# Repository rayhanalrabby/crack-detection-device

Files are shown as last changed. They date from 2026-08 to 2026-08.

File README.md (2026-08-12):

# Crack Detection Device

A low-cost ultrasonic surface-crack detector: an HC-SR04 on an Arduino
Uno inside a custom 3D-printed enclosure. Built as an accessible
alternative to commercial NDT equipment, which starts around €100 and
runs far higher for professional units.

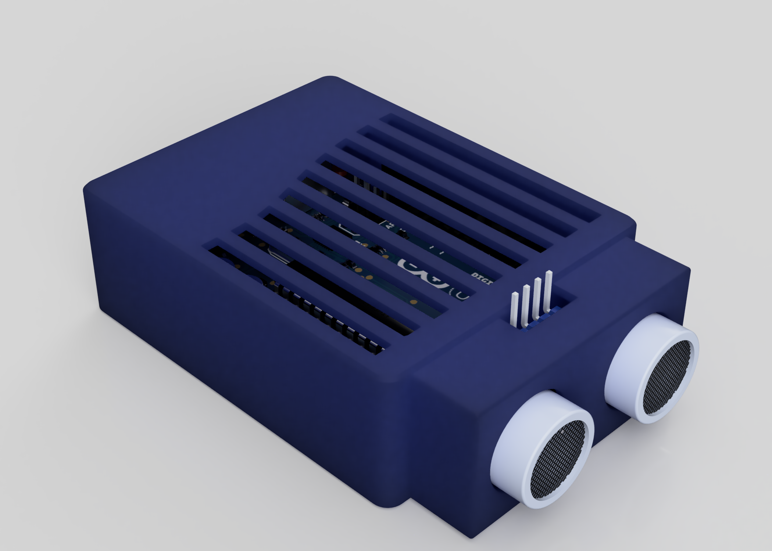
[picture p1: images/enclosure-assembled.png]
Enclosure


## Why

Commercial crack detection works — ultrasonic pulse flaw detectors and
eddy current testers both do the job well — but they're priced for
professional inspection contracts, which puts them out of reach for
small projects and routine checks.

A pre-development survey of construction, manufacturing, and QA
workers alongside home-improvement users found the two most-wanted
features were **portability** and **low cost**, ahead of severity
classification and data logging. That result set the design brief:
small, simple, cheap.

The project targets UN SDG 9 (Industry, Innovation and Infrastructure).
Undetected structural cracks carry a real cost — the Rana Plaza
collapse in 2013 followed visible wall cracks that were dismissed the
day before the building came down.

## How it works

The HC-SR04 emits ultrasonic pulses and times the echo. Swept across a
surface, a crack registers as a spike in measured distance: the sound
path lengthens where the surface recedes. The Arduino IDE's serial
plotter renders this live, so a crack appears as a visible deviation
from an otherwise flat trace.

| No crack | Crack detected |
|:---:|:---:|
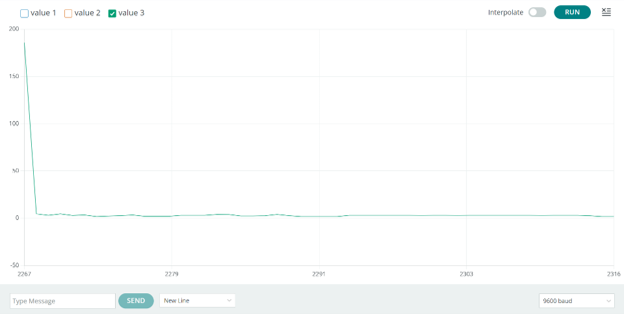
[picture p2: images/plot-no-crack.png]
Flat trace
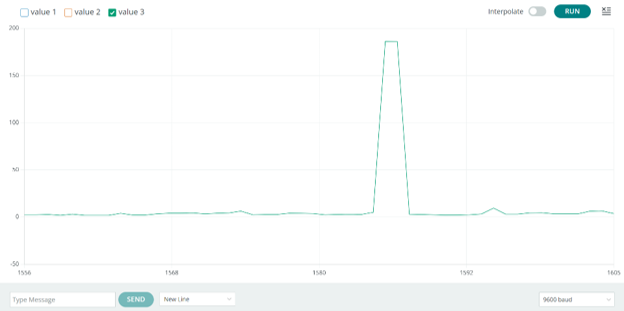
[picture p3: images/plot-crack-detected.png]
Spike
|  |  |

## Sensor validation

Before building anything, the sensor was checked against its datasheet
claim of ±3 mm accuracy across 2–400 cm. Testing focused on the short
end of that range, since surface crack detection never uses the rest.

| Actual (cm) | Measured (cm) | Error (cm) |
|---|---|---|
| 0.5 | 0.49 | 0.01 |
| 1.0 | 1.04 | −0.04 |
| 2.0 | 1.99 | 0.01 |
| 2.5 | 2.35 | 0.15 |
| 3.0 | 3.01 | 0.01 |
| 3.6 | 3.59 | 0.01 |
| 8.0 | 7.79 | 0.21 |

Worst case 2.1 mm, inside the datasheet's 3 mm. Worth noting the
readings at 0.5 cm and 1.0 cm sit below the sensor's rated 2 cm
minimum and shouldn't be treated as valid — the HC-SR04 has a blind
zone there where the echo returns before the receiver settles.

## Enclosure

Designed in Fusion 360 around the Arduino Uno's mounting footprint,
printed in PLA as a two-part snap-fit shell.

<p align="center">
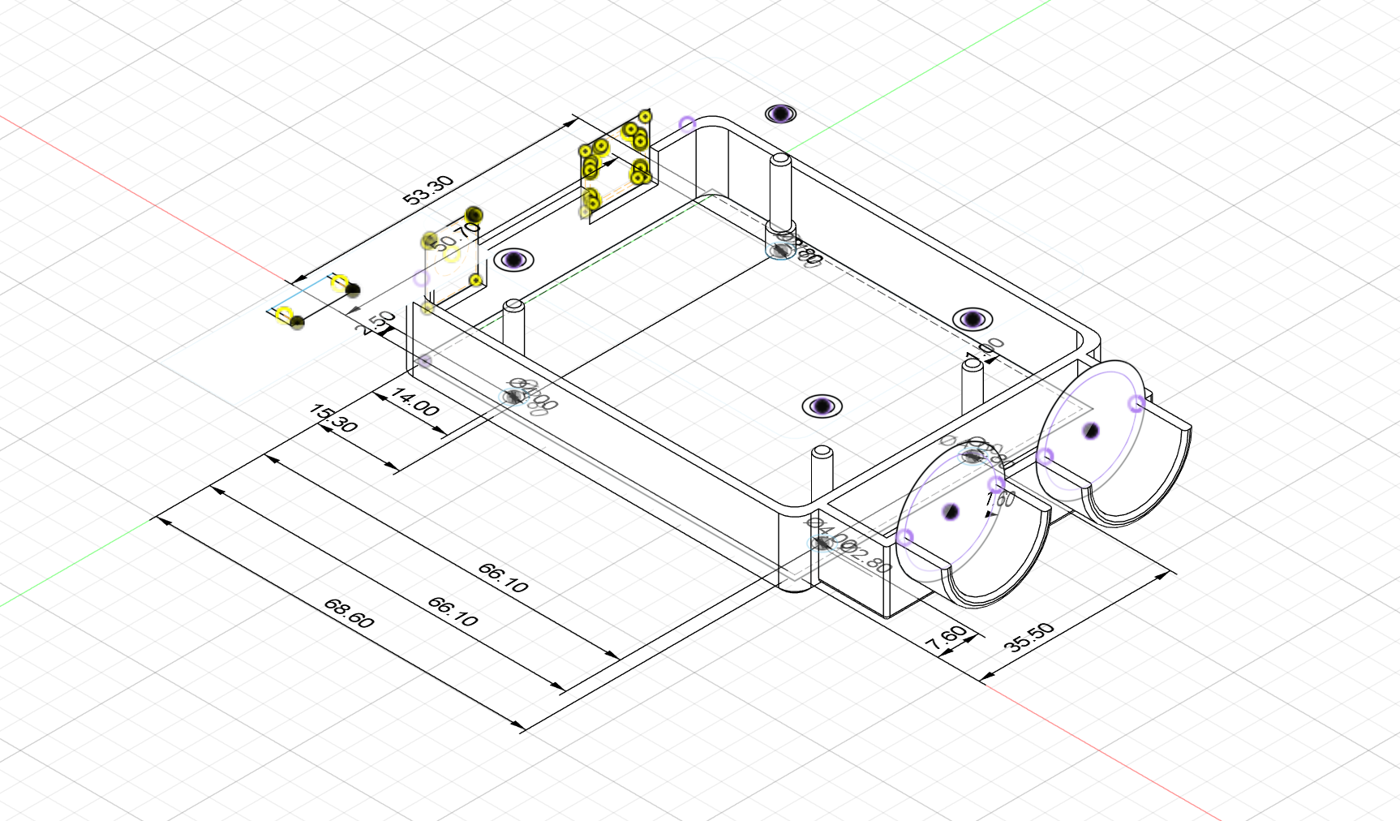
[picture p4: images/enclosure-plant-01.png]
  
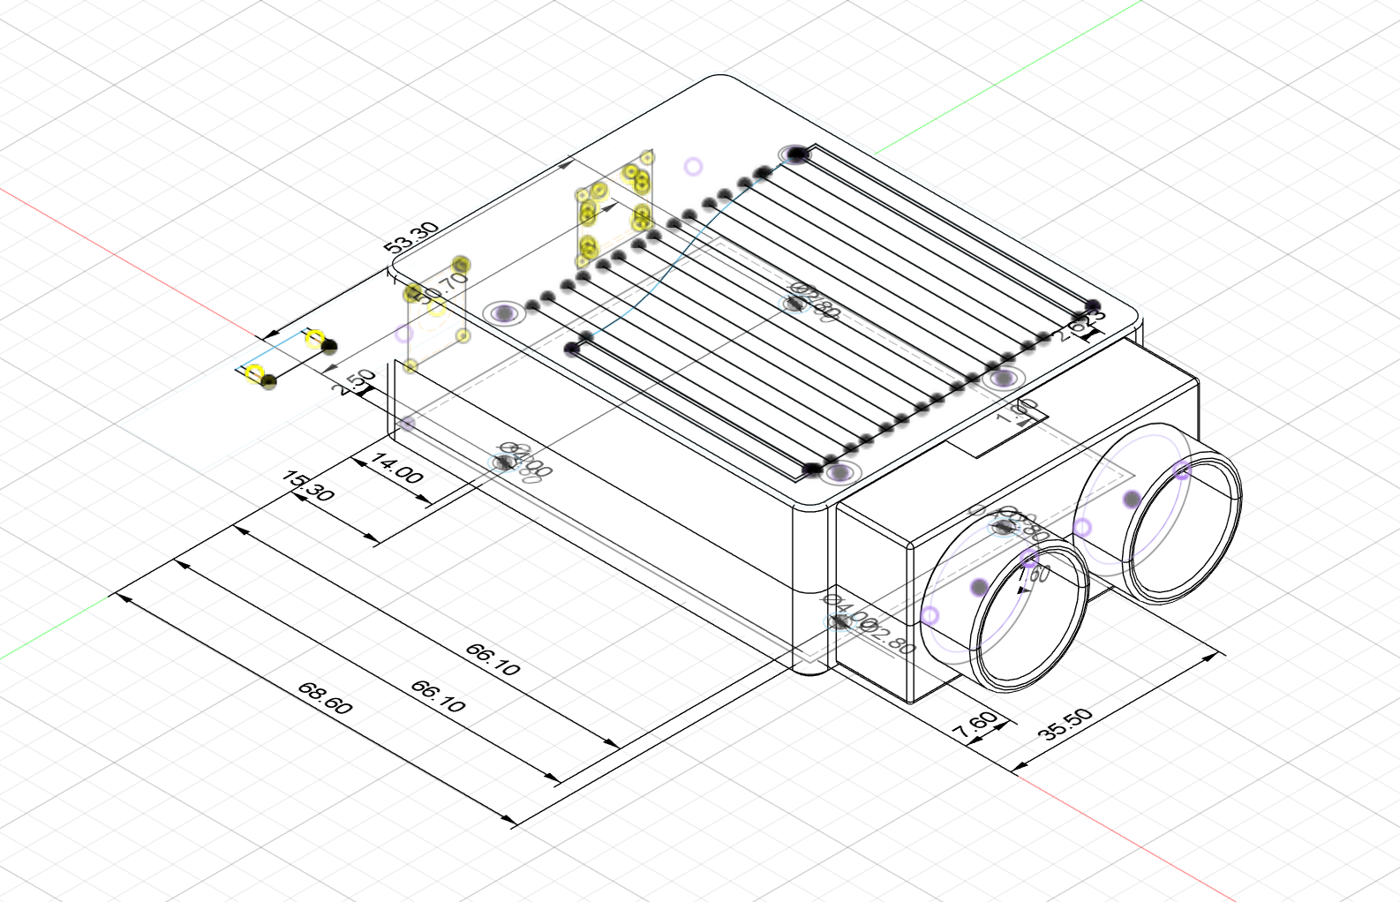
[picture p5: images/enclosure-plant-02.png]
  
</p>

| Feature | Value | Reasoning |
|---|---|---|
| External | 68.6 × 53.3 × 22.0 mm | Arduino footprint plus clearance |
| Wall thickness | 1.6 mm | Exactly 4 perimeters at a 0.4 mm nozzle |
| Internal clearance | 1.0 mm | Print shrinkage and insertion tolerance |
| Mounting pins | Ø2.8 mm | Under the board's Ø3.2 mm holes — friction fit, not press fit |
| Standoffs | Ø4.0 × 4.0 mm | Keeps solder joints off the floor |
| Snap-fit overlap | 4.0 mm, chamfered | Guides pins in, prevents print damage on assembly |
| Ventilation | 9 slots, 3.5 mm | Airflow without compromising the shell |

Every dimension was chosen against a manufacturing constraint rather
than picked by eye. The 1.6 mm wall is two perimeters either side at a
0.4 mm nozzle — strong without wasting material. The pins are
deliberately undersized against the Arduino's holes so the board
friction-fits and can still be removed.

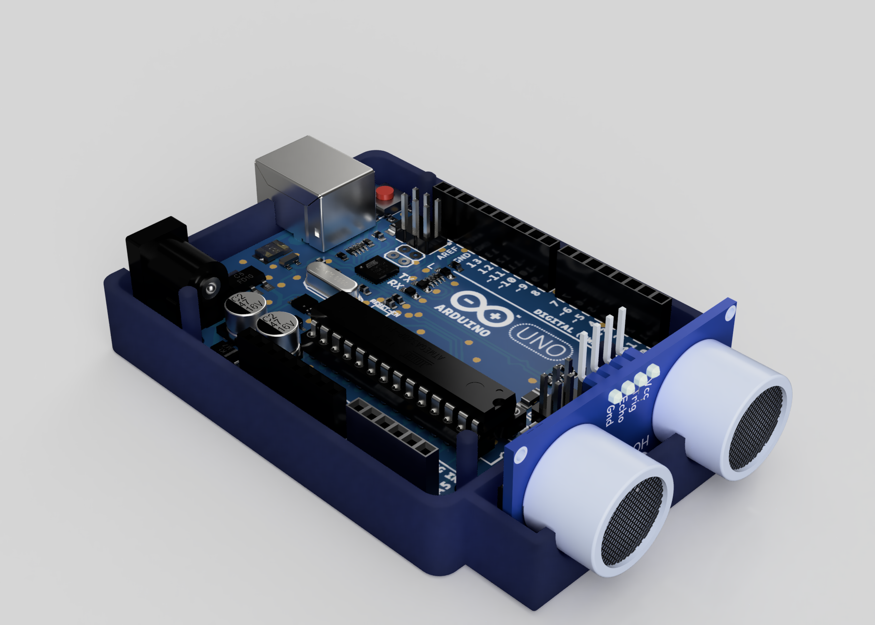
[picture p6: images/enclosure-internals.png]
Internals


The sensor housing extends 12.6 mm from the body with the barrel
seated 9.0 mm deep, holding the transducers at fixed geometry relative
to the enclosure — important, since sweep distance is the measurement.
Cut-outs on the top expose the programming header, so the board can be
reflashed without opening the case.

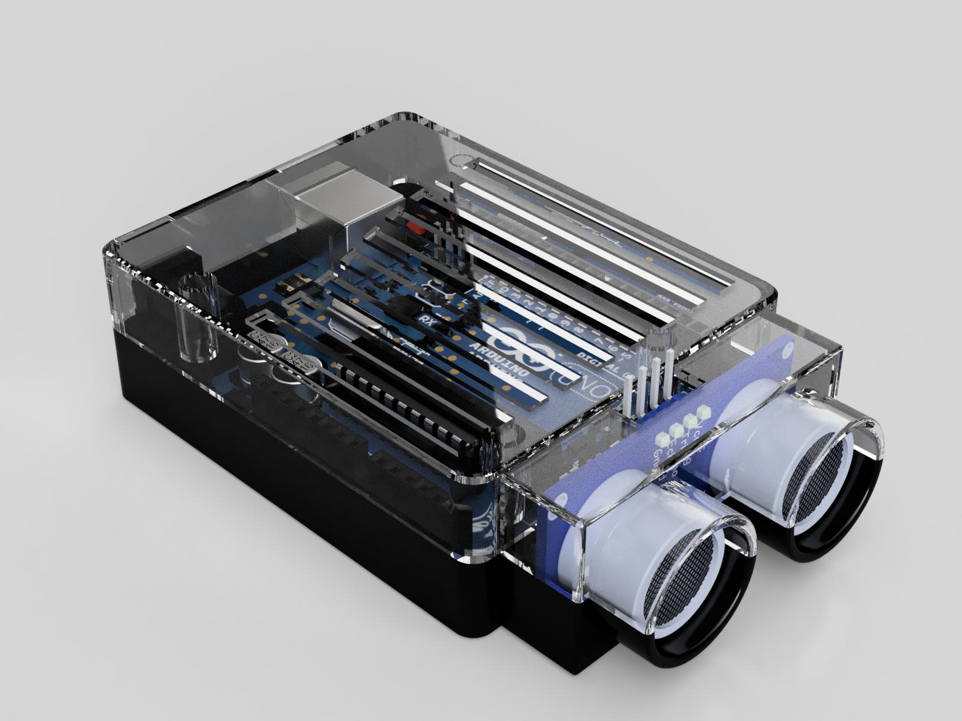
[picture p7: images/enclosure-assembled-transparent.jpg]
Transparent view


## Validation with users

A post-development survey put the prototype in front of the same kinds
of users as the initial one. Feedback was positive on ease of use and
build quality, with two recurring requests: **data storage** across
repeated checks on one area, and **more detailed output** for
reporting.

Both had ranked below portability and cost in the pre-development
survey. They only surfaced as priorities once people had something in
their hands — which is the case for building the prototype at all
rather than designing from the first survey and stopping.

## What I'd change

- **The device detects surface geometry, not cracks.** A step, a seam,
  or a texture change produces the same spike as a fracture. Nothing
  distinguishes them, which limits it to guided use on surfaces the
  operator already knows should be flat.
- **No severity classification**, despite it ranking third in user
  demand. Depth and width determine whether a crack matters, and a
  single-point distance reading gives neither.
- **Sub-2 cm readings are outside the sensor's rated range** and were
  included in the accuracy table anyway. They shouldn't have been.
- **Detection is by eye, off a plotter.** No thresholding, no logging,
  no output beyond a live graph — precisely the two things users asked
  for after handling the prototype.

## Hardware
Arduino Uno · HC-SR04 ultrasonic sensor · 3D-printed PLA enclosure

## Files
- `src/crack_detector.cpp` — sensor firmware
- `cad/` — printable enclosure, two parts (snap-fit)
- `docs/technical-report.pdf` — research, testing, design, survey data
- `docs/problem-specification.pdf` — original project brief
- [`media/enclosure-render.mp4`](media/enclosure-render.mp4) — enclosure render
- [`media/presentation-recording.mp4`](media/presentation-recording.mp4) — group presentation
- `images/` — renders, dimensioned drawings, serial plots

---

EE397 Project-Based Learning, Maynooth University, Year 3 Semester 1
(Dec 2025). Group of 3 — my contribution: enclosure design (Fusion 360
modelling, dimensioning, print preparation), firmware, and research.
Full team credited in the report.

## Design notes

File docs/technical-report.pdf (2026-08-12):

## Crack Detection

## EE397 Technical Report

## Group 5: Patricia Ehigiamusoe Shakirat Olayode Md Rayhan Mia

## Facilitator: Vahid Fakhari

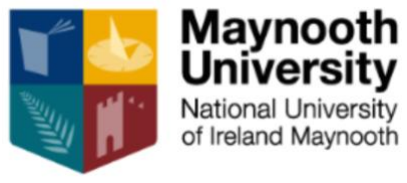
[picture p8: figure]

19/12/2025

## Department of Electronic Engineering Maynooth University

## ABSTRACT

The aim of this report is to present a possible solution to a societal issue, aligned with the Sustainable Development Goals (SDGs). The solution must be well researched and extensively tested to determine how well is addresses a certain issue or part of an issue. Sustainable infrastructure is a key part of any type of construction. From physical buildings to web applications, every developer works to have infrastructure that is easily maintainable and will not fail unexpectedly. One aspect of maintenance is testing for irregularities. This should be done during development as well as on a regular basis after development is complete.
Looking at the area of infrastructure sustainability, we decided on a crack detection device. Such a device detects surface level cracks within a degree of accuracy. This report details our findings in this area as well as our efforts to create a crack detecting device.
Throughout this report, the research behind a crack detection device and the construction of our device will be demonstrated.

## TABLE OF CONTENTS

## 1. INTRODUCTION

Crack, break, fracture, split. These are not words we want to hear in any building or manufacturing process. Nowadays, we are so used to seeing cracks all around us. For example, in our homes, in buildings, and on bridges. Some are big, but many are so small we don’t think twice about them. But these miniature fractures can lead to major issues if left unchecked and the first step in addressing any problem is being aware of the problem. This is our motivation for developing a crack detection device. We are aware that many versions of similar devices exist. However, they are usually expensive and therefore not accessible for projects with a smaller budget. By developing a device at a lower cost and that is simple to use, we hope to make crack detection more accessible.
This aims of this project align with the 9

th Sustainable Development Goal (SDG), Industry, Innovation, and Infrastructure. We will reflect on the social and environmental impact cracks and fractures have on infrastructure.
In this report, we will discuss the theoretical aspect of crack detection as well as the technical work carried out to create a prototype device.

## 2. REPORT LAYOUT

The rest of this report is structured as follows:

- In section 3, a detailed review of the crack detection field is investigated. Examples of existing devices are looked at. This provides a strong basis for the project to be built on.
- Section 4 covers the ethical considerations surrounding this project, including a related Sustainable Development Goal (SDG), Industry, Innovation and Infrastructure. This section aims to examine the role of maintenance and sustainability in society.
- In section 5, customer input is gathered via survey. An analysis of public awareness and opinion of infrastructure issues and their solutions provide valuable insights into the necessity of this project.
- In section 6, the development of our first prototype is discussed. This includes sensor testing and the design of an external cover.
- Section 7 presents customer feedback of the prototype. A new post-development survey is compared to the initial survey carried out at the beginning of the project.
- Finally, section 8 highlights the main findings of this project in a conclusion. Possible further works are also explored in this section.

## 3. LITERATURE REVIEW

Looking at available crack detection devices will further broaden our understanding of crack detection technology and how such a device would need to be developed. This review will explore different types of crack detection which will help us decide the best option to use for our project.

3.1. Concrete Ultrasonic Pulse Flaw Detector

The Concrete Ultrasonic Pulse Flaw Detector for Crack Depth and Width is a device sold by GAOTek [1]. It is advertised as an “advanced ultrasonic flaw detector with 1-12,000mm range”. Some of the parts it consists of are an LCD, a crack width probe, a crack depth gauge scale and couplant. The device works by reading the data with the transducer (probe) and displaying it on screen. A couplant (gel like substance) is used to improve the transmission of ultrasonic waves between the probe and material being tested [2]. There is no price listed for this product, there is only an option on their website to request a quote. However, we can imagine the price point of a device like this would be high.

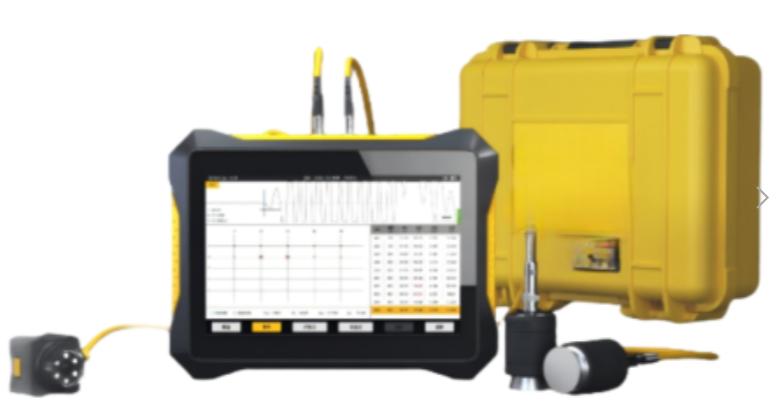
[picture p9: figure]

Figure 1: Concrete Ultrasonic Pulse Flaw Detector for Crack Depth and Width

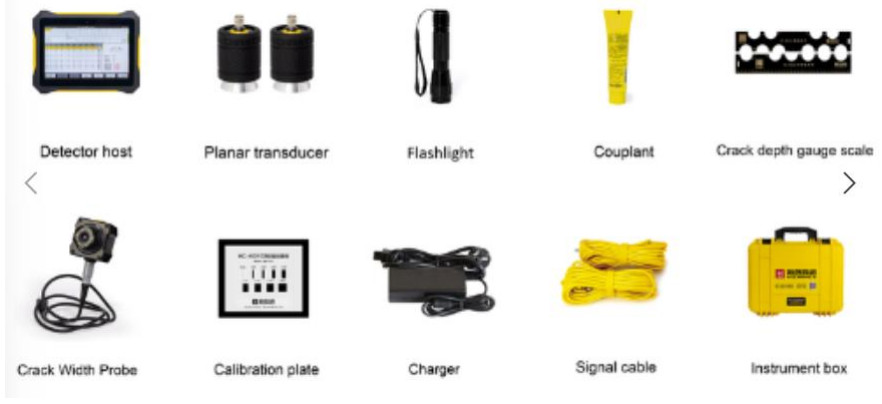
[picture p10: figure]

Figure 2: Parts included in Concrete Ultrasonic Pulse Flaw Detector

3.2.Eddy Current Testing (ECT)

Crack detecting products developed by Eddyfi Technologies use a technique called eddy current testing (ECT) [3]. ECT involves a passing alternating current through a copper wire which creates a magnetic field around the wire [4]. The current in the wire and the magnetic field oscillate at the same frequency. If the coil is brought near other conductive materials, the opposing currents create eddy currents. Defects are detected by analysing the change in the magnetic fields. They state that is type of testing offers “fast inspection of surface-breaking cracks”.

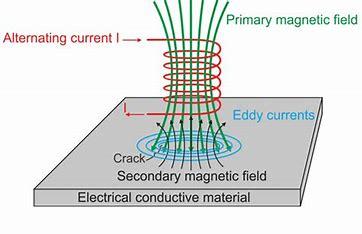
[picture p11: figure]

Figure 3: Eddy Current Testing (ECT)

By researching some available methods of crack detection, we have settled on using an ultrasonic sensor for our project. The straight-forward approach of the sensor is suitable for this project. The Arduino ultrasonic sensor can be easily coded and tested with a compatible microcontroller.
Ultrasonic crack detection which is a method of non-destructive testing (NDT) [5]. NDT is a form of testing that does not impact the test material, unlike destructive testing. Destructive testing evaluates the test material properties by forcing the properties (e.g. tensile strength) to reach their limit.

## 4. ETHICAL CONSIDERATIONS

4.1.Sustainable Development Goals (SDGs)

Part of the given criterion for this project was to provide a potential solution to a community-based problem. The Sustainable Development Goals (SDGs) are a set of seventeen global goals arranged by the United Nations [6]. These goals seek to tackle various global challenges, like No Poverty, Zero Hunger, Quality Education, and many more. The SDGs act as a “universal call to action to end poverty, protect the planet, and ensure prosperity for all” [6].
For this assignment, we choose to consider the 9th Sustainable Development Goal, ’Industry, Innovation, and Infrastructure’. The aim of this goal is to “build resilient infrastructure, promote inclusive and sustainable industrialisation and foster innovation” [7]. A crack detector device can be used to test the integrity of materials before, during and after construction.
4.2. Societal Problems

A societal problem is defined as “a condition or situation that negatively affects a significant number of people in society” [8]. Poor infrastructure conditions is an issue many people face. Many of the buildings we live and work in are left in poor conditions which can be a danger to people in them. In extreme cases the buildings can become unusable and left abandoned. This is a problem that can stem from different issues including the presence of small cracks or faults which worsen over time. One correct procedure to deal with such an issue is to regularly check the state of a building with a device like a crack detector to identify areas before they intensify.

With our device a user will be able to detect the issue early, limiting the potential permanent damages. The simple design and functionality make it easy to use so it’s use is not restricted to just professionals.

4.3. Environment

Cracks and other structural defects play a major role in our environment today, more than we realise. The structural defects in buildings and other establishments have far-reaching impacts on the societal and economic infrastructure of the world. It affects public safety, service continuity and long-term development. The lack of considerations regarding the severity of “minor cracks” can lead to major safety issues and injuries or in some extreme cases death.
Examples of such cases include the collapse of the eight-storey Rana Plaza Factory in Bangladesh on 23rd April 2013. The building was evacuated due to the appearing of cracks in the walls the day before this mishap. However, as a result of failure to recognise the severity of the situation, workers were permitted back inside the following day. Disastrously, the building collapsed and resulted in significant loss of life [9]. The presence of these external cracks indicate that the structural integrity of the building had been compromised prior to this incident. If the cracks were detected earlier, the situation could have potentially been avoided.
There are multiple others severe cases similar to the Rana Plaza Factory case. For example, a sinkhole in Thailand in September 2025 [10] and the collapse of a bridge in China in July 2024 [11]. All these fatalities developed from construction oversights, including inadequate planning and insufficient long-term structural considerations. Over time, the emergence of cracks and structural decay led to fatal outcomes.
A possible solution to problems like this is a crack detector device. With this device, it is simple to check for cracks in most structures. This device is one step closer to a safer living environment.

## 5. CUSTOMER INPUT

When developing a product for public use, it is vital to consider who the end user will be. The target audience we looked at included professionals working in fields like construction, manufacturing and quality control, as well as people who engage in advanced home projects. We wanted a device that is suitable for both these groups. We first organised a collection of questions to ask people who might use a device like this. When choosing the questions, we wanted to assess the participants knowledge of crack detection and explore what features they would like in the device. We conducted a short survey to inform decisions later on in the project. The results of this survey are detailed below.

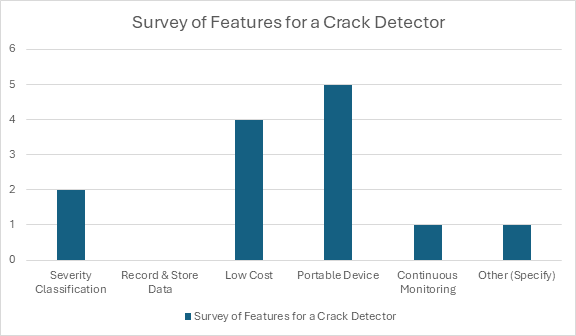
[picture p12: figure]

Figure 1: Desired Features in a Crack Detector from Survey

The graph above (Figure 1) shows the desired features chosen by the participants. They were given multiple options and could pick as many as they like. The most popular choice was a portable device. Another common choice was low cost. The customer input gathered from this survey defined the design of our prototype. We aimed to make the device small, easy to handle, portable and at a low price since those were the features chosen by most of the participants.

Outside of device features, 80% of respondents said they had heard of crack detecting tools. All participants said they would trust a device to detect cracks. This represents a level of trust and expectation in modern technology. People expect devices to be accurate and function well. This is something we considered when creating a prototype.

## 6. PROTOTYPE DEVELOPMENT

6.1. Sensors

Sensors are input devices that can monitor physical signals and detect different types of changes in the environment. They are crucial inspecting the behaviour of a system and detecting unanticipated actions or failures in a system [12]. There are multiple different types of sensors but for this project we settled on using an ultrasonic sensor.

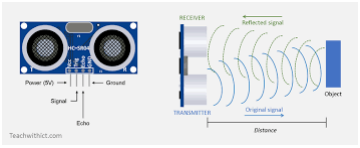
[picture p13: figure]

Figure 2: Ultrasonic Sensor

For the circuit, the HC-SR04 Ultrasonic Sensor was used. This sensor measures the distance by emitting high frequency sound waves and detecting their echo’s. The datasheet of the sensor claims the sensor can detect objects in the range of 2cm – 400cm [13]. By placing this sensor opposite a surface within the range of detection, it can detect cracks using the sound waves.

6.2. Circuit Design

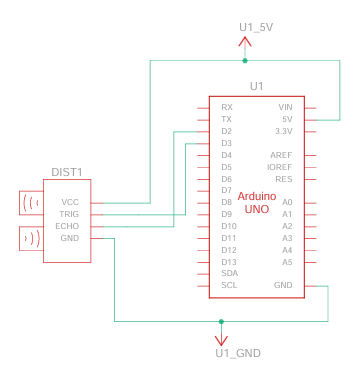
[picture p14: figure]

Figure 3: Circuit Wiring of Ultrasonic Sensor with Arduino UNO

The circuit components were composed of an ultrasonic sensor and an Arduino UNO microcontroller board. The code was written using the Arduino IDE [14]. The IDE provides a serial monitor and serial plotter. The monitor was used to check the printed distance values. The serial plotter was used to make a live graph of the data read from the ultrasonic sensor.

6.3. Testing Ultrasonic Sensor Accuracy

Since choosing to use an ultrasonic sensor, we needed to confirm the sensor we got operates as expected. The datasheet for the HC-SR04 Ultrasonic Sensor claims the operating range of the sensor is approximately 2cm to 400cm with ±3mm accuracy [15]. This test focuses on the lower side of the range. As the device is small, it will be limited to detecting smaller cracks. Therefore, the full range of the sensor will not be used. The details of the test to inspect the datasheet values are explained below.

Equipment Needed:

- Ultrasonic sensor
- Tape measure
- Arduino Uno
- Computer with Arduino IDE installed
- Object for sensor to detect

Method

- Choose a distance, measure the distance with a tape measure and record the value.
- Place an object at one end of the measured distance and the ultrasonic sensor at the other end.
- Run the code in Appendix C for the sensor to print values to the serial monitor and record the value.
- Comparing the actual distance to the value from the ultrasonic sensor distance to get the difference [Equation 1].
Difference = Actual distance − Ultrasonic sensor distance | [Equation 1]
Results
Actual Distance (cm) | Ultrasonic Sensor Distance (cm) | Difference (cm)
2 | 1.99 | 0.01
8 | 7.79 | 0.21
0.5 | 0.49 | 0.01
1 | 1.04 | -0.04
2.5 | 2.35 | 0.15
3 | 3.01 | 0.01
3.6 | 3.59 | 0.01

Table 1: Ultrasonic Sensor Accuracy Test Results

The result of the test shown in the table above (table 1), show the sensor is quite accurate. The biggest difference was 0.21cm, which converts to 2.1mm. This value is within the ±3mm error from the datasheet. It can be concluded that the ultrasonic sensor operates as expected.

6.4. Simulations

The below figures (figure 4 and figure 5) are graphs of the distance measured when a crack is not present and when it is present. It is displayed using the serial plotter tool in the Arduino IDE. The x-axis is the time in microseconds. The y-axis is the measured distance in mm.

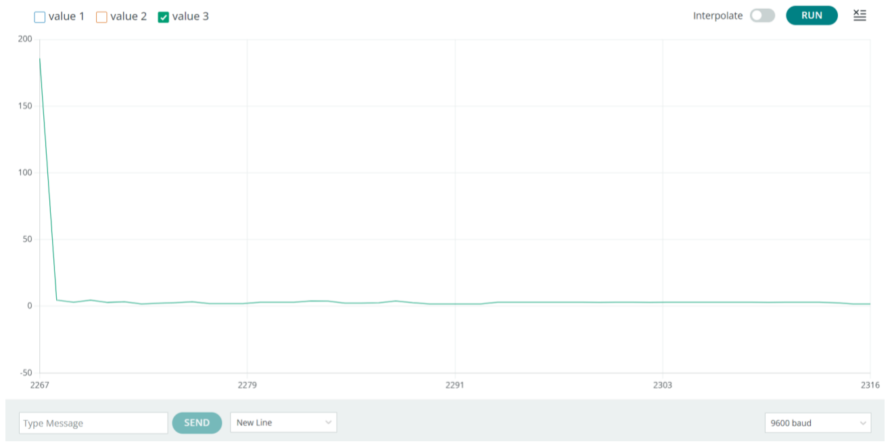
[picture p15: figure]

Figure 4: Graph showing no crack detected

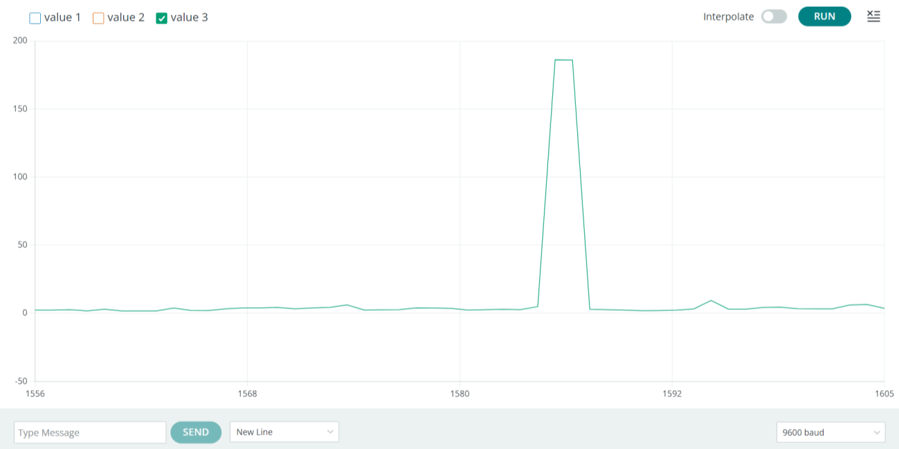
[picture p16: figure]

Figure 5: Graph showing crack detected

6.5.Enclosure Design

The enclosure for the Arduino Uno and HC-SR04 ultrasonic sensor used in the crack detection prototype was designed using Fusion 360. Factors influencing the enclosure design included the mounting geometries of the Arduino Uno, the automatic manufacturability of the enclosure, and the results of the crack detection system pre-development survey. Survey respondents stressed the need for a portable, low-cost, and user-friendly system. The housing design of the electronics began with a Google Sketchup workflow of an Arduino Uno dimension drawing (shown below) with modifications to accommodate the ultrasonic sensor.
Design Methodology
Using the two-point rectangle and dimensioned mounting holes of the external footprint of the Arduino Uno, the enclosure geometry was created. Prior to shelling, internal clearance (wiggle room) must be included. This eases assembly and prevents over-constraining or excessive friction as the Arduino board is slid into place. The enclosure body was then extruded at a fixed height and automatically shelled, resulting in a uniform component thickness. The body was then split in half at the mid-plane automatically and snap-fitted together with printed mounting pins and mounting holes.

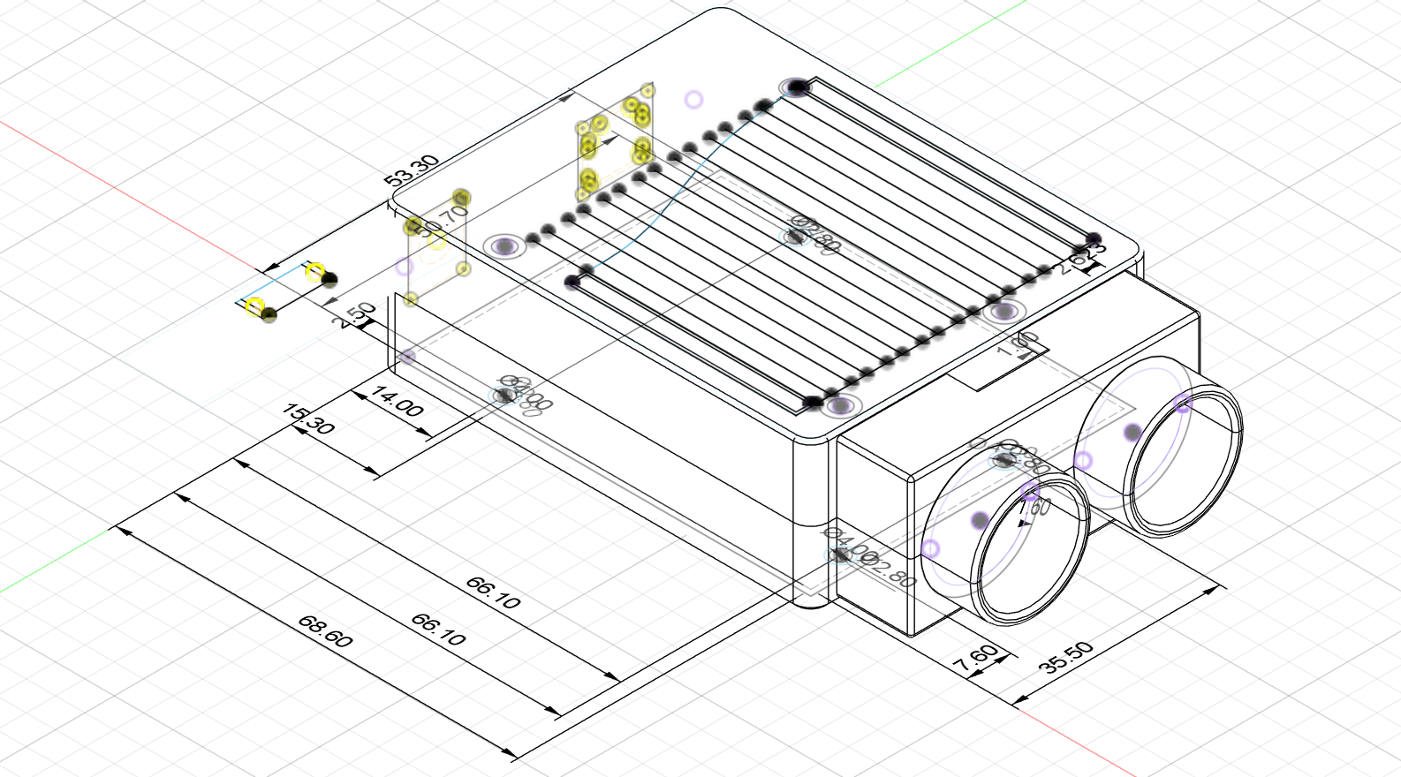
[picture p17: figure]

Figure 4: Dimensioned CAD model of the whole enclosure

Main Enclosure Body Dimensions

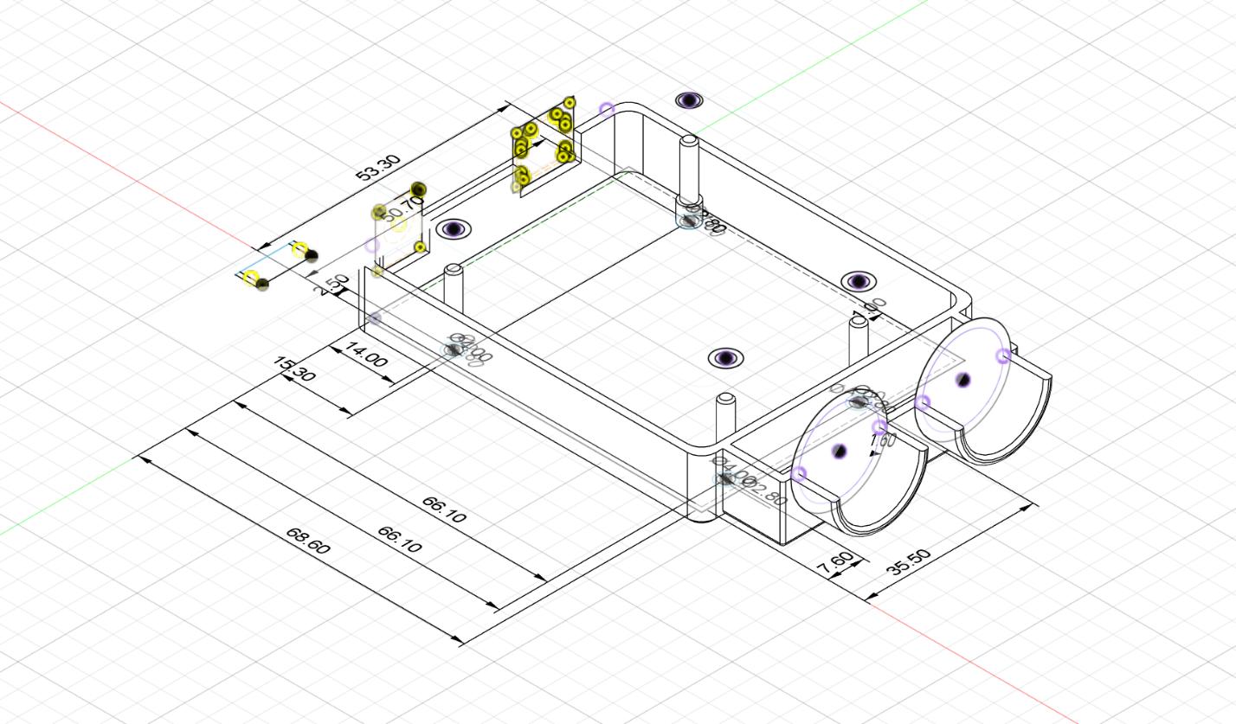
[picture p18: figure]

Figure 5: Dimensioned CAD model of the bottom part of the enclosure

External Dimensions

- Overall enclosure length: 68.60mm
- Overall enclosure width/height: 53.30mm
- Enclosure height (extrusion): 22.00mm
These dimensions are for the outer enclosure body and exclude the ultrasonic sensor housing.

Wall Thickness and Clearance

- Wall thickness (shell): 1.6mm
- Internal clearance (wiggle room): 1.0mm
The 1.0 mm clearance was accounted for by offsetting the Arduino reference geometry prior to the shelling operation. This also accounts for manufacturing tolerances, 3D printing.

shrinkage and ease of insertion and removal of the board. The wall thickness of 1.6 mm is equivalent to two shells around the perimeter in a 0.4 mm nozzle, making the wall strong while minimising material.

Mounting Pillars and Arduino Interface

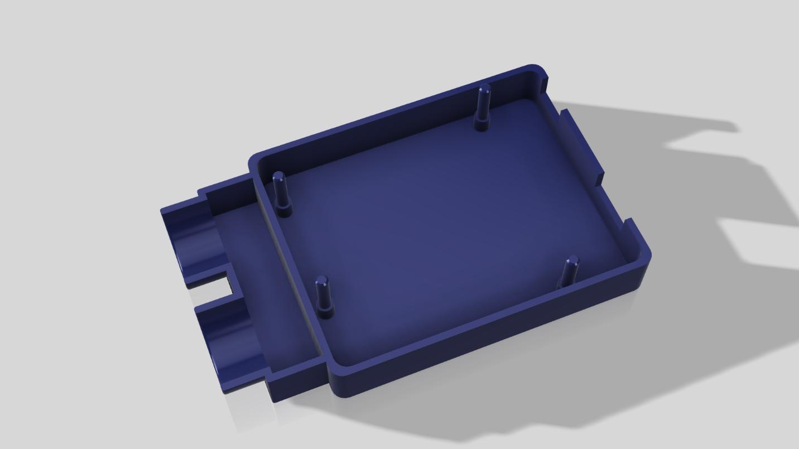
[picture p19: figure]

Figure 6: 3D model of the bottom part of the enclosure highlighting mounting pins

Mounting Pins

- Modelled mounting pin diameter: Ø 2.80mm
- Actual diameter of Arduino mounting pin: Ø 3.20mm
The smaller pin diameter allows light friction fit into the board instead of a press fit.

Mounting Pillar Placement
The following are the dimensions between the centres of the mounting pillars:
- Horizontal distance between mounting pillar centres: 66.10mm
- Distance between the tops of the top and bottom mounting pillars: 50.70mm
The remaining positional offsets describe where the pillars lie relative to the enclosure reference edges:
- Offsets: 14.00 mm, 15.30mm
- Vertical offset from lower reference edge: 2.50mm
These values match those of the Arduino Uno mounting pattern in the design tutorial.

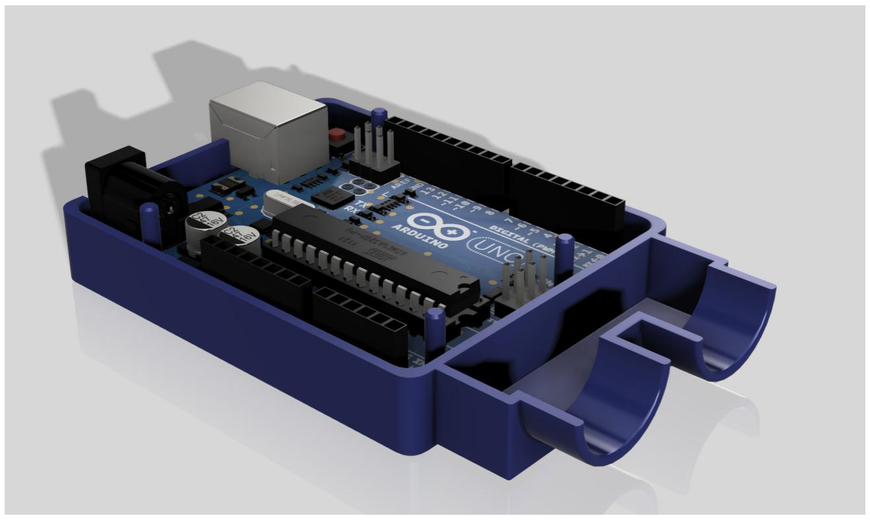
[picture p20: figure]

Figure 7: 3D model of the bottom part of the enclosure highlighting Arduino’s position on it

Standoffs and Structural Support

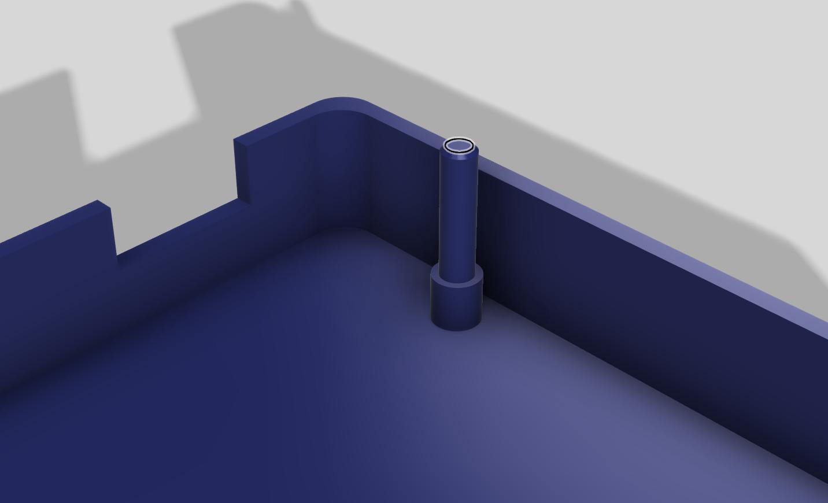
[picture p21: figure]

Figure 8: 3D model of the enclosure highlighting Standoffs

To prevent the Arduino PCB from touching the bottom of the enclosure (the solder joints and components on the board's underside), cylindrical standoffs were used.

- Standoff diameter: 4.0mm
- Standoff height: 4.0mm
These standoffs have the purpose of supporting the Arduino and providing stable alignment with cut-outs.

Top and Bottom Assembly Features

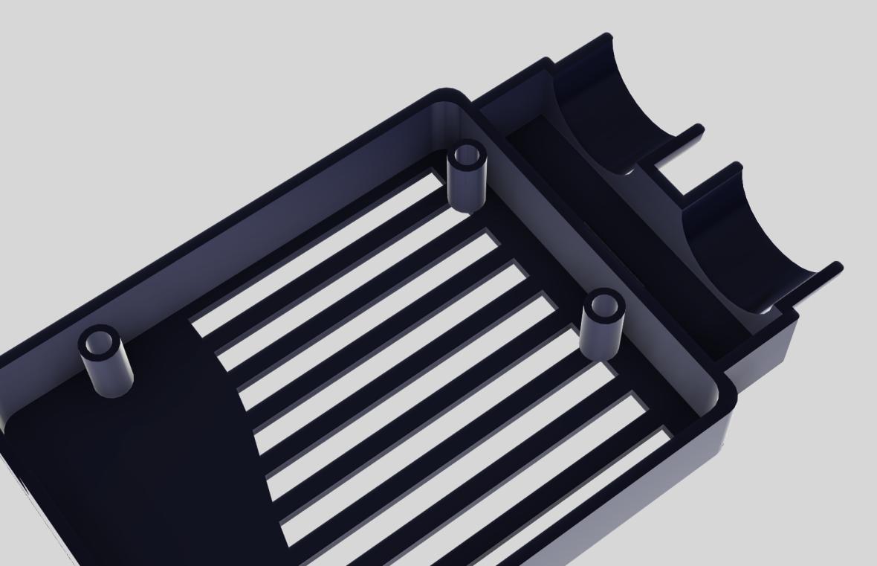
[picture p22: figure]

Figure 9: 3D model of the enclosure highlighting mounting pin receiving hole

The enclosure employs an interference-assisted snap-fit design:

- Pin overlap beyond the mounting split plane: 4.0mm
- Receiving hole diameter (top half): 5.2mm
- Receiving hole depth: 10.0mm
- Chamfer on mounting pins: 4.0mm
Chamfers were also added to help guide the pins into the receiving holes, making assembly easier and preventing damage to the prints in the process.

Ultrasonic Sensor Housing Integration

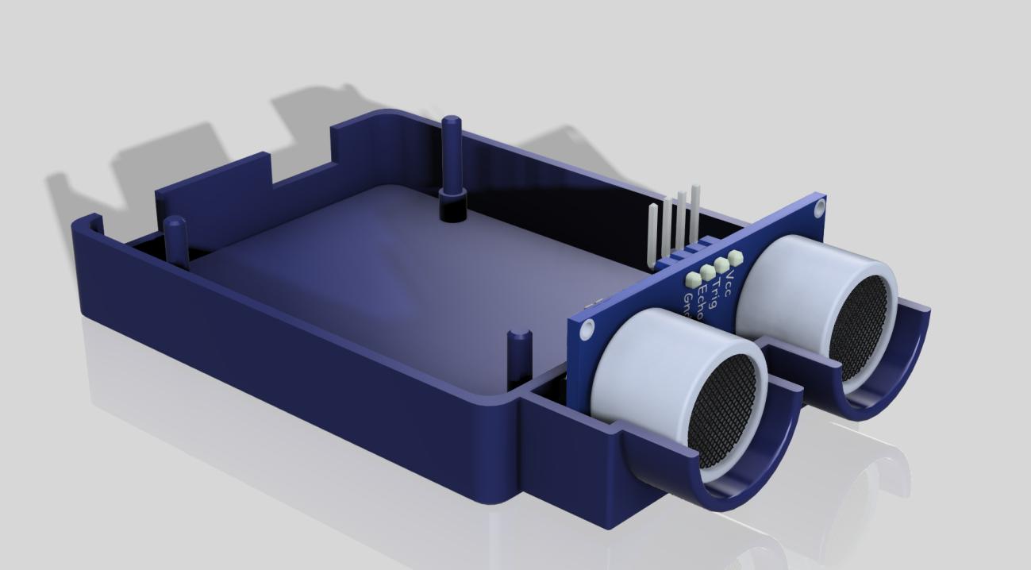
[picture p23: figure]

Figure 10: 3D model of the enclosure highlighting Ultrasonic Sensor Housing Integration

An extension was designed to install the HC-SR04 ultrasonic sensor in front of the enclosure's body, aligned with it.
The measured dimensions of the ultrasonic sensor housing are as follows:
- Front extension length from the main body: 12.621mm
- Sensor barrel insertion depth: 9.02mm
- Front bezel / ring thickness: 3.625mm
Two circular holes are provided that are aligned with the ultrasonic transmitter and receiver so that no obstructions would interfere its operation. This also maintains the geometry of the sensor with respect to the enclosure body.

Ventilation and Access Features

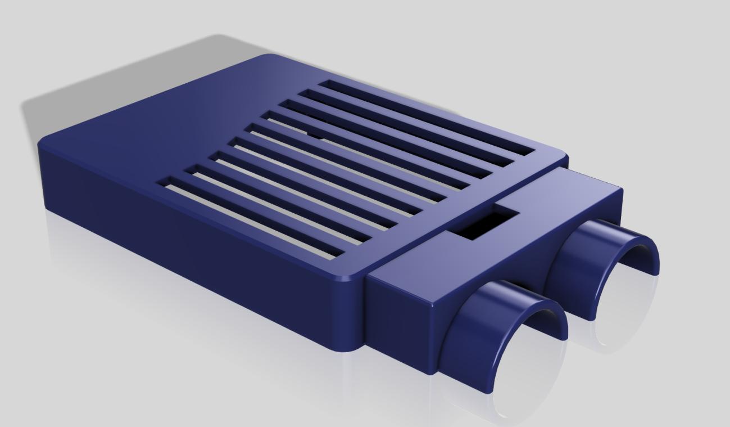
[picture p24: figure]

Figure 11: 3D model of the enclosure highlighting Ventilation and Access Features
To allow airflow to prevent overheating during operation, ventilation slots were also cut into the top cover:
- Slot opening width: 3.5mm
- Spacer width between slots: 2.5625mm
- Number of openings: 9
- Total vent length about 52mm
Extra cut-outs on the top surface allow direct access to the Arduino's programming and debug header pins without having to remove the lid of the enclosure.

Design Considerations and Manufacturability

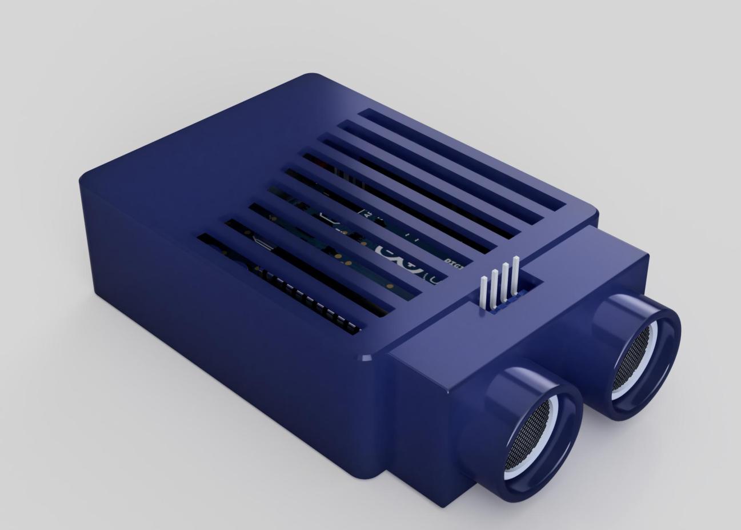
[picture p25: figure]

Figure 12: 3D model of the enclosure

The design of the enclosure was performed for additive manufacturing, using consistent wall thickness, large gaps, and chamfered edges to ensure a good result from the 3D printer and ease of assembly. The quantity of material was minimised to meet environmental targets while retaining required strength.

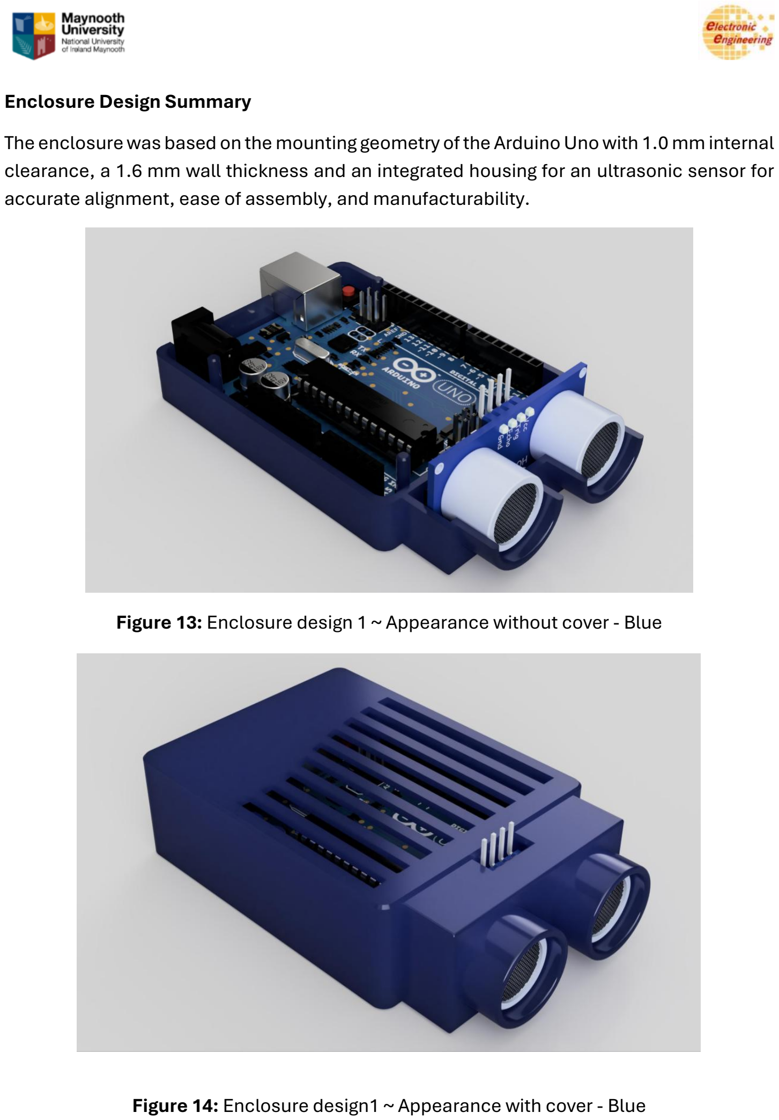
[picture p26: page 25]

Enclosure Design Summary
The enclosure was based on the mounting geometry of the Arduino Uno with 1.0 mm internal clearance, a 1.6 mm wall thickness and an integrated housing for an ultrasonic sensor for accurate alignment, ease of assembly, and manufacturability.

Figure 13: Enclosure design 1 ~ Appearance without cover - Blue

Figure 14: Enclosure design1 ~ Appearance with cover - Blue

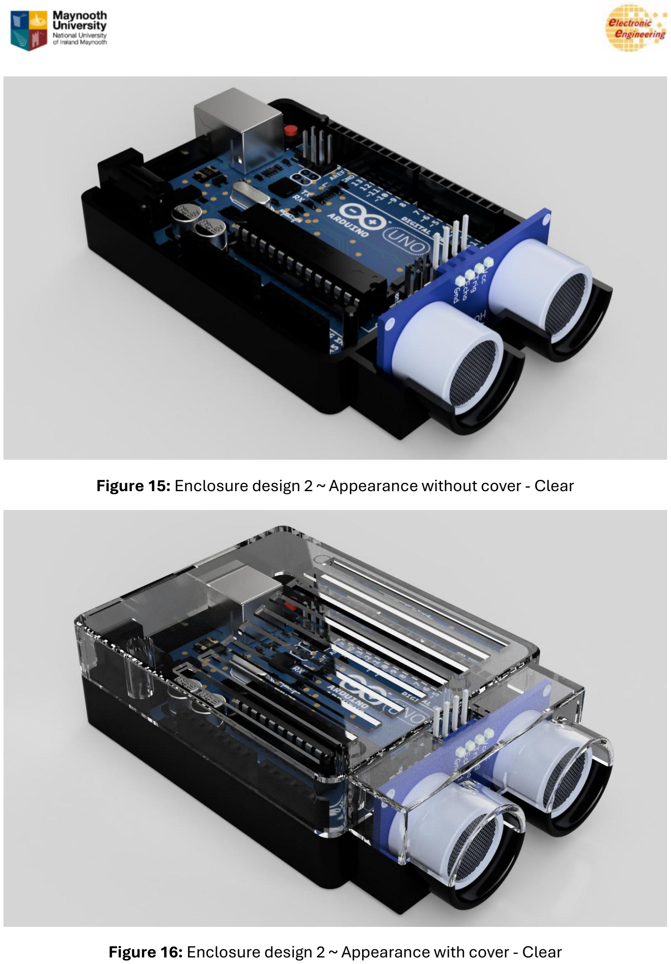
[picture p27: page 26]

Figure 15: Enclosure design 2 ~ Appearance without cover - Clear

Figure 16: Enclosure design 2 ~ Appearance with cover - Clear

## 7. Customer Feedback

To understand how the product would be used in real- life situations we got the customers feedback on our device. We collected responses from a variety of people including professionals in fields such as Construction, Manufacturing and quality control, as well as people who take on advances home improvement projects. These results allowed us to understand how different users might interact with the project.
As we did before in the customer input, we created a questionnaire for people who have interacted with the device. The feedback showed a range of experience levels, with professionals generally having more familiarity with crack detection that home users. Nonetheless, similar views and priorities were recognised across both groups. Many users mentioned the ease of use, good design, reliability and practical features that make the device suitable for the desired fields. In addition, portion of respondents also said they would like the data to be easy to store in the device in cases of multiple checks in one area and more detailed output for easier reporting.
This feedback helped to understand the product reflects the needs and expectation of its intended users. It helped to identify the most important features to users. With the customer feedback we would be able to update our product in accordance to the needs and wants of the target audience.

Figure 17: Desired Features in a Crack Detector from Survey

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
Is there anything else you would like it to do?

Wanting Smore storage | Detailed data | No request

## 8. CONCLUSION

As part of this project, background research, customer survey, sensor experiments and prototypes have been undertaken, in keeping with United Nations, Sustainable Development Goal 9: Industry, Innovation, and Infrastructure, to show that early crack detection is a relevant social issue and technically feasible using low-cost hardware.
The pre-development survey identified that a large proportion of people are aware of cracks but do not have the knowledge or equipment to effectively assess their severity. Cost and portability were identified as two of the main barriers to the uptake of current crack detection technologies. The research also helped define the impact on the design of the resulting prototype which needed to be simple, low cost, and easy to use. This simplicity was confirmed by the results of the post-development feedback which said that the device looked practical, reliable and suitable for inspections.
The HC-SR04 ultrasonic sensor was tested, and it was found that the accuracy of its readings was well within limits determined by its datasheet. These limits are especially valid at small distances such as those it would be used at for crack detection on the surface. This establishes ultrasonic sensing as a viable option for the crack detection system. Additionally, a custom enclosure design has been created to fit the Arduino Uno and ultrasonic sensor with more compact protection, with an emphasis on correct sensor alignment, assembly and manufacture.
The prototype could possibly also find use in profiling structures and infrastructure, as well as detecting the early stages of structural failure. Although not a replacement for specialist structural analysis equipment, it could be used as a simple and potentially powerful early warning system against possible faults in a given structure. This could help prevent small structural cracks developing into failure.
Further work can be done in improving the accuracy of crack detection through more precise sensors or different sensing technologies. Other improvements include classification of crack severity, increased data storage, and the addition of wireless communication. Improvements to the enclosure and environmental sealing may allow for deployment of the system outdoors and long-term usage.
In conclusion, this project shows that a low-cost, simple crack detection device can be developed and employed to improve infrastructure safety and longevity in a more sustainable way.

## 9. References

[1] Concrete Ultrasonic Pulse Flaw Detector For Crack Depth and Width – GAOTek Concrete Ultrasonic Pulse Flaw Detector For Crack Depth and Width - GAOTek - GAO Tek (https://gaotek.com/product/concrete-ultrasonic-pulse-flaw-detector-for-crack-depth-and-width-gaotek/) (accessed October 2025).
[2] Couplant Ultrasonic Couplants for NDT Testing | Sonagel Range | Sonatest (https://sonatest.com/products/couplant) (accessed
October 2025).
[3] Eddyfi Technologies for Cracking Inspection Applications Crack Detection - Eddy
Current Crack Detection | Eddyfi (https://www.eddyfi.com/en/application/crack-detection) (accessed October 2025).
[4] Eddy Current Testing (ECT) Eddy Current Testing (ECT) | Eddyfi (https://www.eddyfi.com/en/technology/eddy-current-testing-ect) (accessed October
2025).
[5] Non-Destructive Testing (NDT) – Process, Types & Applications Explained Non-
Destructive Testing (NDT) | Process, Types & Applications | Fractory (https://fractory.com/non-destructive-testing/) (accessed October
2025).
[6] The 17 Goals THE 17 GOALS | Sustainable Development (https://sdgs.un.org/goals) (accessed November 2025).
[7] Industry, Innovation and Infrastructure Goal 9: Industry, Innovation and Infrastrucure | The Global Goals (https://globalgoals.org/goals/9-industry-innovation-and-infrastructure/) (accessed December 2025).
[8] Defining Social Problems: Key Perspectives from Sociologists Key perspectives from
Sociologists | Social Work Institute (https://socialwork.institute/society-social-institutions-social-problems/defining-social-problems-sociologists/) (accessed December 2025).
[9] Rana Plaza Factory collapse resulting in death of 1,000 people Bangladesh factory
collapse: calls reform regarding workers rights and safety standards | EBSCO (https://www.ebsco.com/research-starters/history/2013-rana-plaza-collapse) (accessed
December 2025).
[10] Bangkok Sinkhole: Soil entered metro tunnel due to damaged station ceiling, says governor Bangkok sinkhole: Soil entered metro tunnel due to damaged station ceiling, says
governor | The Straits Times (https://www.straitstimes.com/asia/se-asia/road-collapses-near-bangkoks-chao-phraya-river-no-injuries-reported-so-far) (accessed December 2025).
[11] Bridge under construction in China collapses into Yellow River, Bridge under construction in China collapses into Yellow River, killing at least 12 people, state media say
- CBS News (https://www.cbsnews.com/news/china-bridge-collapse-yellow-river-video-state-media-say-6-deaths/) (accessed December 2025).
[12] Hardware Sensor Hardware Sensor - an overview | ScienceDirect Topics (https://www.sciencedirect.com/topics/computer-science/hardware-sensor) (accessed
October 2025).

[13] How HC-SR04 Ultrasonic Sensor Works & Interface It with Arduino How HC-SR04 Ultrasonic Sensor Works & How to Interface It With Arduino (https://lastminuteengineers.com/arduino-sr04-ultrasonic-sensor-tutorial/) (accessed November 2025).
[14] Arduino IDE arduino.cc/en/software/ (accessed November 2025).
[15] HC-SR04 Ultrasonic Sensor Module User Guide HC-SR04-Ultrasonic.pdf (https://www.handsontec.com/dataspecs/HC-SR04-Ultrasonic.pdf) (accessed November 2025).

## APPENDIX

Appendix A: Pre-Development Survey Responses

Survey Response 1
1. Are you aware of any technology or device that detects cracks?
No, I have never used a device like that.
2. Would you trust a device to detect cracks?
Yes, I've used devices like stud detectors before, and they work well.
3. Which of these features would you like in such a device?
a. Crack severity classification (minor, moderate, severe)
b. Record and store data from session to playback later
c. Low cost
d. Portable device
e. Continuous monitoring
f. Other (Specify)
c - portable device, d - low cost
4. How likely would you be to use this device?
I probably wouldn't use it. I usually just fill cracks at home without giving it too much thought so I wouldn't really be interested in getting one.
5. Where would you use this device?
I'm not in construction or anything like that by profession so I would probably only use it at home if I had to get one.
6. Any other comments/suggestions?
How much would a device like this usually cost?
Responded: The lowest price I’ve seen is about €100.

Survey Response 2
1. Are you aware of any technology or device that detects cracks? Yes, but I have never used one before.

2. Would you trust a device to detect cracks?
Yes, especially when it’s not easy to see, like inside a material.
3. Which of these features would you like in such a device?
a. Crack severity classification (minor, moderate, severe)
b. Record and store data from session to playback later
c. Low cost
d. Portable device
e. Continuous monitoring
f. Other (Specify)

a – severity classification, c – low cost, d – portable, e – continuous monitoring
4. How likely would you be to use this device?
Yes, it would be useful for work.
5. Where would you use this device?
I would use it at work my workplace and at home for personal projects.
6. Any other comments/suggestions?
No

Survey Response 3

1. Are you aware of any technology or device that detects cracks? Yes, I’ve used tech like that.
2. Would you trust a device to detect cracks?
Yes, technology is always more reliable than people.
3. Which of these features would you like in such a device?
a. Crack severity classification (minor, moderate, severe)
b. Record and store data from session to playback later
c. Low cost
d. Portable device
e. Continuous monitoring
f. Other (Specify)
d – portable, f – Other: highly accurate and reliable
4. How likely would you be to use this device?
Very likely, but only if I found it better than the equipment I use now.
5. Where would you use this device?
I work in quality assurance, so I use tools like this at work.
6. Any other comments/suggestions?
7. It’s very useful to be able to see exactly where a fault is early in production.

Survey Response 4

1. Are you aware of any technology or device that detects cracks? Yes, I know of a couple tools that can detect cracks.
2. Would you trust a device to detect cracks?
Yes, manually inspections can be really time consuming.
3. Which of these features would you like in such a device?
a. Crack severity classification (minor, moderate, severe)
b. Record and store data from session to playback later
c. Low cost
d. Portable device
e. Continuous monitoring
f. Other (Specify)
a – classification, c – low cost, d - portable
4. How likely would you be to use this device?
It’s something I would like to have and not need rather than need and not have.
5. Where would you use this device?
Probably at home and at work.
6. Any other comments/suggestions?
No.

Survey Response 5

1. Are you aware of any technology or device that detects cracks? Yes, but I don’t have one.
2. Would you trust a device to detect cracks?
Yes, as long as it’s decently accurate.
3. Which of these features would you like in such a device?
a. Crack severity classification (minor, moderate, severe)
b. Record and store data from session to playback later
c. Low cost
d. Portable device
e. Continuous monitoring
f. Other (Specify)
c – low cost, d - portable
4. How likely would you be to use this device?
I would use it if I had one.
Responded: Why don’t you have one?
I’ve looked at a few devices, but they were a bit out of my price range.
5. Where would you use this device?

I would use it at work.
6. Any other comments/suggestions?
No.

Appendix B: Post-Development Survey Responses

Survey Response 1

1. Does this device look like something you would use?
Yes, it looks like something I would use. It seems sturdy and designed for practical work.
2. Is there anything you would change in the design?
Maybe make add a handle so it’s easy to carry around during jobs.
3. Does the device work the way you expect it to?
Yes, it works pretty much how I expected it to.
4. Is there anything else you would want it to do?
Saving previous results would be useful when checking the same area more than once.
5. How likely would you be to use this device?
I’d be fairly likely to use it when needed.
6. Any other comments/feedback?
It seems reliable for hands-on use.

Survey Response 2

1. Does this device look like something you would use? Yes, especially for inspections or assessments.
2. Is there anything you would change in the design?
Yes, I would make curve in the side for better grip.
3. Does the device work the way you expect it to?
Mostly yes, once you understand how to position it properly.
4. Is there anything else you would want it to do?
Being able to store and export data would be useful.
5. How likely would you be to use this device?
I would probably use it fairly regularly.
6. Any other comments/feedback?
It feels like something designed for professional environments.

Survey Response 3

1. Does this device look like something you would use?

Yes, I could see myself using it.
2. Is there anything you would change in the design? Not much, the design makes sense for field use.
3. Does the device work the way you expect it to? Yes, it does what it’s supposed to do.
4. Is there anything else you would want it to do? Nothing major, it already covers what I’d need.
5. How likely would you be to use this device? Probably now and then, depending on the project.
6. Any other comments/feedback?
It looks durable enough for regular on-site use.

Survey response 4
1. Does this device look like something you would use? Possibly, mainly for more detailed checks.
2. Is there anything you would change in the design? Nope it looks very industrial which suits.
3. Does the device work the way you expect it to?
It works fine but there is a bit of a learning curve.
4. Is there anything else you would want it to do?
A more detailed feedback (from the device) would be helpful for reporting.
5. How likely would you be to use this device?
Not all the time, but useful in specific cases.
6. Any other comments/feedback?
No.

Survey Response 5
1. Does this device look like something you would use?
Yes, definitely. It looks reliable and well suited for repeat checks.
2. Is there anything you would change in the design?
No major changes – it feels well thought out.
3. Does the device work the way you expect it to?
Yes, it performed as expected.
4. Is there anything else you would want it to do?
Tracking results over time would be useful.
5. How likely would you be to use this device?
Very likely, especially when monitoring the same areas.

6. Any other comments/feedback?
It looks like something that would fit well into regular professional workflows.

Appendix C: Code
Ultrasonic sensor code

// C++ code
int trig = 3;
int echo = 2;

long duration; //For echo reading float distance; //For ultrasonic sensor

void setup()
{
pinMode(trig, OUTPUT);
pinMode(echo, INPUT);
Serial.begin(9600);
}

void loop()
{
distance = calcDistance();
Serial.print("Distance = "); Serial.println(distance);
delay(300); //Delay for 300 microsecond (3 seconds) }

float calcDistance()
{
digitalWrite(trig, LOW);
delayMicroseconds(2);
digitalWrite(trig, HIGH); //Set trig HIGH for 10 microseconds delayMicroseconds(10);
digitalWrite(trig, LOW);
duration = pulseIn (echo, HIGH); //Read echo
distance = (duration * 0.034) / 2;
return distance;
}

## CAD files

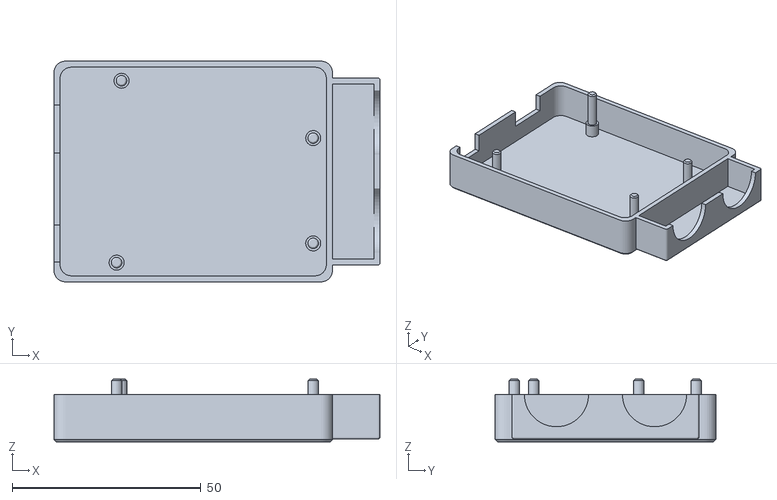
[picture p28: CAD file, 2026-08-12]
cad/enclosure-bottom.stl
86.4 x 58.5 x 16.6

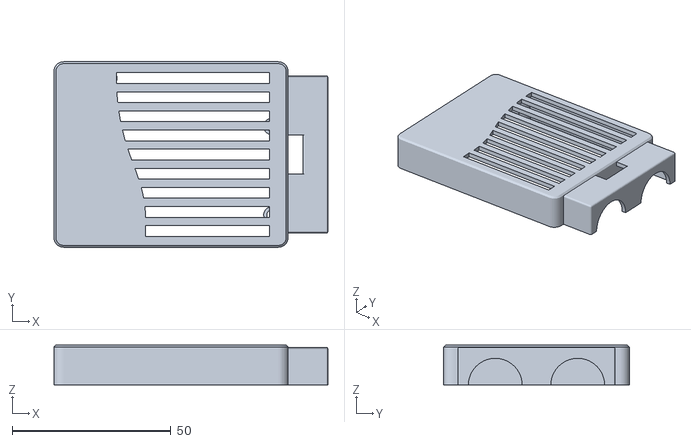
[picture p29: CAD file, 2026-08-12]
cad/enclosure-top.stl
86.4 x 58.5 x 12.6

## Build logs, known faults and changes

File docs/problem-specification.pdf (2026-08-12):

## Crack Detection EE397 Problem Specification Report

## Group 5: Patricia Ehigiamusoe Shakirat Olayode Md Rayhan Mia

## Facilitator: Vahid Fakhari

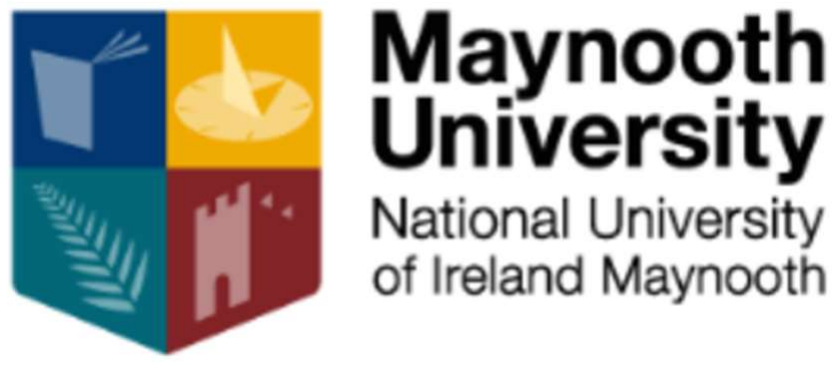
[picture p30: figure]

21/10/2025

## Department of Electronic Engineering Maynooth University

2

## ABSTRACT

Infrastructure encompasses many of the facilities and services we use every day, especially in the public sector. Telecommunication towers, gas pipelines, bridges, train tracks and roads are all examples of essential infrastructure we all use every day. All types of infrastructure will have issues at some point. Cracks are one of these issues. Their occurrence is sometimes due to factors like weather conditions, wear and tear over time and poor-quality engineering. If left to grow cracks can lead to detrimental effects on infrastructure as well as people. Ignoring cracks in a derelict apartment building can result in a multitude of injuries and a potential loss to human life. Identifying cracks early can reduce these adverse effects. Regular monitoring is one possible solution. This is the motivation for this project. We will investigate the area of crack detection with the intention and perspective our creating a device that identifies cracks.

3

## Contents

4

## 1. INTRODUCTION

Bridges, roads and buildings are all examples of essential infrastructure we see and use in our everyday lives. We depend on these physical structures to support and improve our existence. Public systems like water, sewage, railways and airports are needed in order for a country to function. [1] Infrastructure dictates the way we travel, transport and work.

Any issues with infrastructure would cause complications and in severe cases could lead to major safety issues or injuries. Recent examples of this include the collapse of a bridge in China in July 2024, and a sinkhole in Thailand in September 2025. The collapse of the bridge in a flood prove area of China was attributed to a steel cable failure and resulted in the deaths of at least twelve people with others reported missing. [2] The sinkhole in Thailand was due to the construction of a metro tunnel and underground stations. [3] While investigations are still ongoing, it has been noted that the collapse was caused by the soil above entering the damaged ceiling of an underground station.

This project aims to research common issues found within infrastructure and develop a practical method to prevent further damage and improve safety by providing early detection. We also intend to create a prototype that is accurate but cost effective. Other possible features will be considered based on research and customer feedback. This will enable us to develop a solid framework to build our project on.
For the purposes of this report, a “crack” will be used to refer to a number of discontinuities within a material. This includes fractures, breaks, faults, etc.

5

## 2. LITERATURE SURVEY

In order to improve our understanding of how an infrastructure inspection tool should work, we will be looking at various established solutions. These examples will help us make informed decisions when designing a prototype in the following areas:
- Which sensors would be most appropriate for the device
- Creating a 3D map that shows cracks
- Features to include in the device
- Displaying information/communicate information to the user
- Recording and storing data
- Transforming data into a simulation

### 2.1 Sensors

While cracks on the surface can be detected by eye, internal cracks are much harder to identify. Both surface and internal cracks should be properly investigated to assess the damage. Non destructive testing (NDT) is a method used to inspect cracks without causing further damage. [4] Ultrasonic Testing
Ultrasonic testing involves the use of ultrasonic waves to check for gaps under the surface of a material. [4] Sound waves are sent through a material by a transmitter. If no gaps are found, the waves are reflected back and received by a receiver. If a gap is found the waves will be reflected back faster. This kind of testing can be very accurate, but its sensitivity means it may not be suitable to use on a non-smooth surface. The sound waves will be reflected back at different points leading to inaccurate results. However, the ease of use and precision of ultrasonic testing make it a popular option when it comes to crack detection.

LiDAR/Creating a 3D Map
LiDAR (Light Detection and Ranging) is another method that is used to measure distances using laser beams. [5] Similar to ultrasonic testing, LiDAR works by sending and receiving waves, in this case light waves. The time taken for the light to return to the sensor is compared to the constant speed of laser light. This allows the distance travelled to be calculated. A LiDAR point cloud is formed from the repetition of this process. [6]

Point cloud data has 3D mapping capabilities, which makes it suitable for mapping surfaces. While this technique is extremely accurate for measuring distances, it is not great for finer details. A solution to this limitation is to combine LiDAR with other sensors. For example, LiDAR and a depth camera can be used together to provide better mapping results. [7] The depth camera can utilise machine learning algorithms to further improve results along with LiDAR. However, these complex networks require a great deal of computation and therefore is not a simple or cost-effective solution to implement.

6

### 2.2 Features

Displaying/Communication Information
There are many different types of crack detector devices available. Most devices typically feature a screen and a probe. [8] The screen may display real time information. Other outputs like sounds and flashing LEDs may be used to communicate things like the device needing to be charged or detecting a crack. Visual and auditory cues often improve a user’s experience with a device, instead of relying only on reading information from the screen. For example, if a battery powered device displays a low power message it can be ignored and forgotten about by the user. Whereas it is much more difficult to dismiss a regular beeping sound.

The monitor for a device using ultrasonic testing might display a crack using a graph. The intensity of the crack is indicated on the y-axis and is plotted against time on the x-axis. [9] The initial transmission of the sound wave is first seen in the graph. Then the reflection of the wave when it reaches the end of the test material is seen at the end (back wall). If a crack is detected, it is shown in between the initial probe and the back wall. The amplitude of the signal depends on the depth of the crack.

Recording and Storing Data
Recording and storing real-time data, allows for the data to be utilised more effectively. When a crack is found it would be useful for the device to record certain values. The value at the peak of the crack and the largest width of the crack would be two values of interest. The cracks could then be categorised depending on these values, with categories such as minor, moderate and severe. Of course, such definitions would need to be based on extensive research and data. Additionally, solutions for each class could be suggested by the device. For example, for a small/minor crack perhaps a suitable solution could simply be to fill it in. Recorded data points can also be used after the initial analysis and after the user has left the site. This data could form part of a report on the inspected crack.

Running a Simulation
Any resilient and sustainable infrastructure must be put under rigorous testing before it can be used. Some tests can be carried out quite successfully on components separately, but this can leave room for the overall build to not function as intended once fully constructed. This is where simulations come in. Simulations are used to replicate real-world events without any real-world consequences. [10] This can be used to test materials or components in important but tough to recreate scenarios. For example, individual steel cables used in bridges can be put under tensile test to identify weaknesses, but how can the entire bridge be effectively tested? A simulation of the bridge could be the answer but only if the simulated environment very closely matches real life.

7

## 3. CUSTOMER INPUT

We recognise that the target audience of crack detector devices would mostly be professionals. As students we ourselves do not have the experience needed to properly identify what is needed in such a device. Therefore, we conducted a short survey to help us cover this gap in our knowledge. The results of this survey are detailed below.

We assumed many people working in industries like construction, manufacturing, quality control and engineering would be familiar with crack detector tools. The first question in the survey was asked to confirm this. 80% of our respondents said they have heard of crack detector tools.

All participants also said they would trust a device to detect cracks. This attitude shows a level of trust in technology. This could be due to technology becoming more advanced with more accuracy than equivalent manual processes. Technology also usually takes less time to perform actions than a person would.

A graph showing the desired features in a crack detector device is shown below (graph 1). The participants were able to choose multiple options.

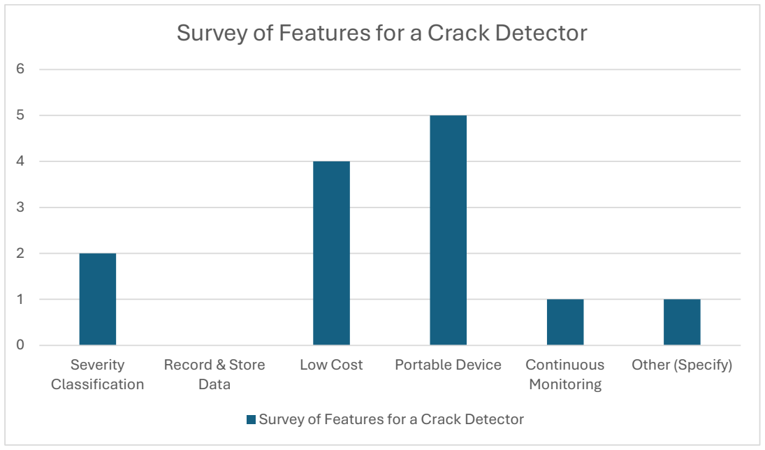
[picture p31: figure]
Severity Classification; Record & Store Data; Low Cost; Portable Device; Continuous; Monitoring; Other (Specify); Survey of Features for a Crack Detector

Figure 1. Desired Features in a Crack Detector The most popular responses were low cost and portable device. 80% of respondents choose low cost and 100% of respondents choose portable device. From research, we found that the average price range of a crack detector device started at around €100 [11] and just went up from there. Top quality detectors can cost up to €7,000. [12]
When asked how likely they would be to use the device and where they would use them, most respondents said they would use it at work. Some also said they would use it at home for home projects.

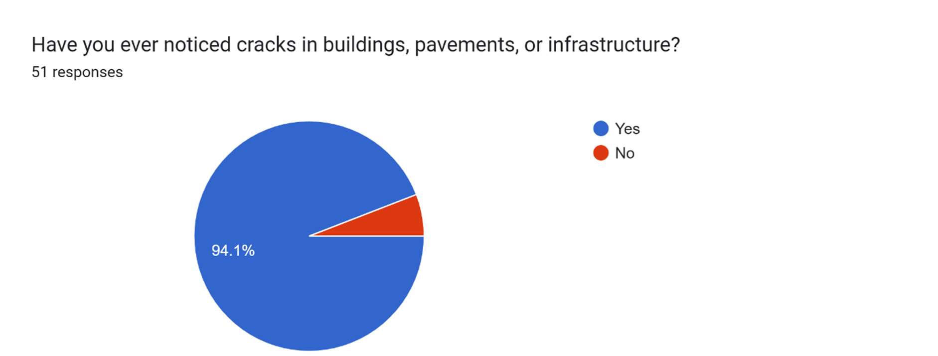
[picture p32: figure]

8

By conducting the survey, we have identified that there is a market for a cheaper product. There is also the option to make the device smaller, so it is more portable. A cheaper device that doesn’t take up much space will also appeal to people involved in home improvement /DIY projects. This opens up a new audience that was not previously considered. We will base our prototype design on the data provided by this survey.

SURVEY 02

A total of 51 participants completed the 2nd survey, representing a diverse group of people from both technical and non-technical backgrounds. This mix ensures that our findings reflect the views of the wider community and not just engineering professionals.

Figure 2. Occupation of survey respondents (n = 51)

Occupation:

The pie chart above reveals that, about 63 % of respondents were students, followed by engineers and architects at 15.7 % the public at, about 11.8 % and a smaller group comprising engineering students and maintenance/facility staff. This shows that although the majority of participants came from a background, we still received input from folks who work hands‑on in maintenance and technical roles. That blend of perspective helped our aim to create a system that’s both educational and practical.

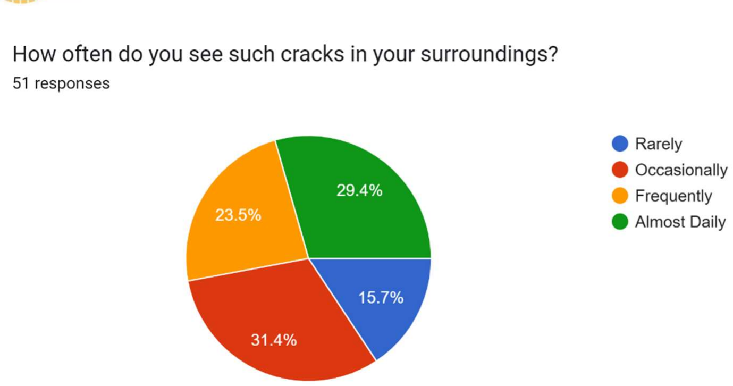
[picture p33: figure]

9

Figure 3. Age distribution of respondents (n = 51)

Age Group:

The second chart shows that the group of respondents—, about 61 %—fall in the age range making it the dominant slice. The next sizeable group, covering a quarter of the sample (25.5 %) spans ages 26‑40 while those 41‑60 account for just under ten percent (9.8 %). Participants under 18 form a fragment of the total. The age breakdown fits the university setting of our questionnaire. It also reveals that the effort attracted responses from career‑oriented professionals and seasoned participants—vital, for assessing usability across a spectrum of ages.

Overall, the survey pulled in a ranging group—students and facility staff, on the user side plus the infrastructure caretakers such as engineers and maintenance teams. That mix lends credibility. Makes the results more relevant, for the sections that follow.

AWARENESS & BEHAVIOUR

To understand how familiar people are with cracks in their surroundings and how they respond to them, we asked participants a series of questions about their awareness and actions.
The questions included:
- Have you ever noticed cracks in buildings, pavements, or infrastructure?
- How often do you see such cracks in your surroundings?
- When you see a structural crack, what do you usually do?
- Do you think cracks can indicate serious safety issues?
- Are you aware of any technology or device that detects cracks automatically?

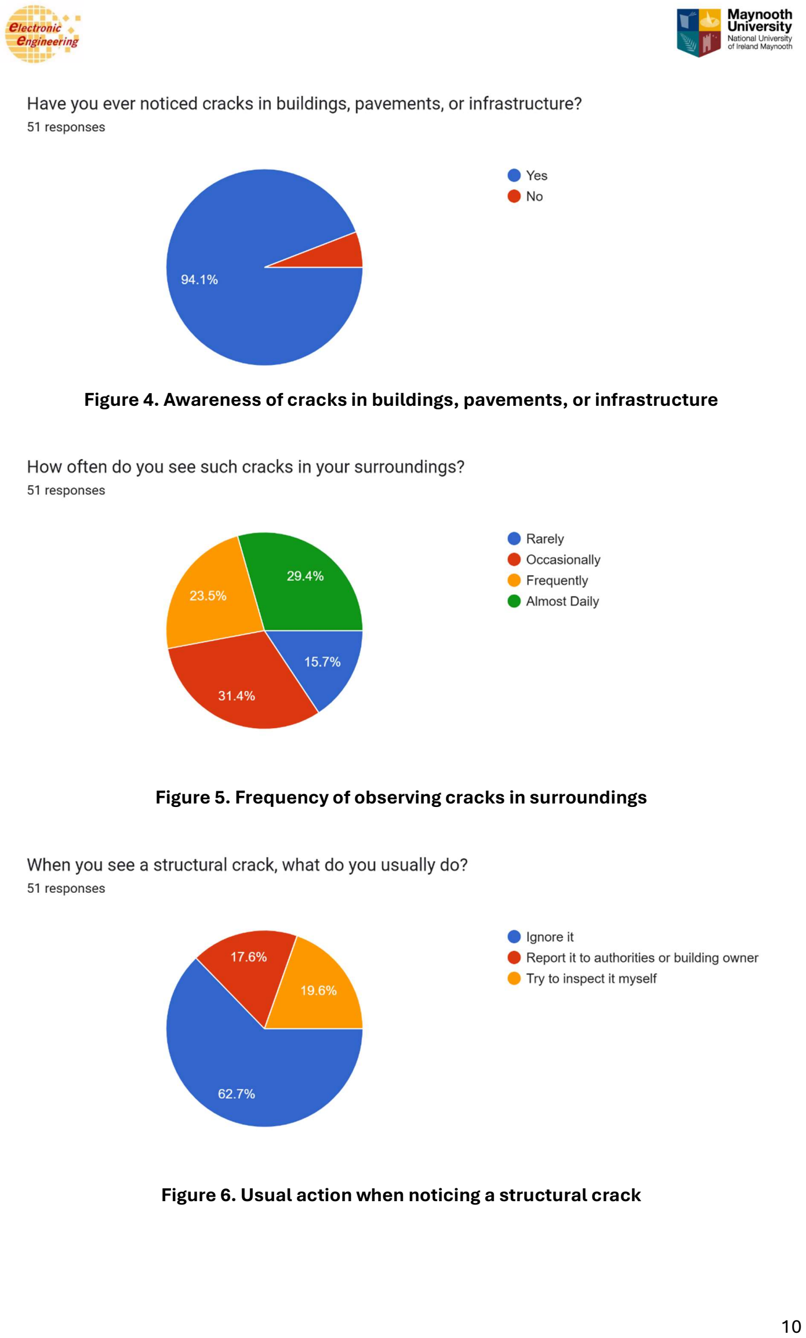
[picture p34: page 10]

10

Figure 4. Awareness of cracks in buildings, pavements, or infrastructure

Figure 5. Frequency of observing cracks in surroundings

Figure 6. Usual action when noticing a structural crack

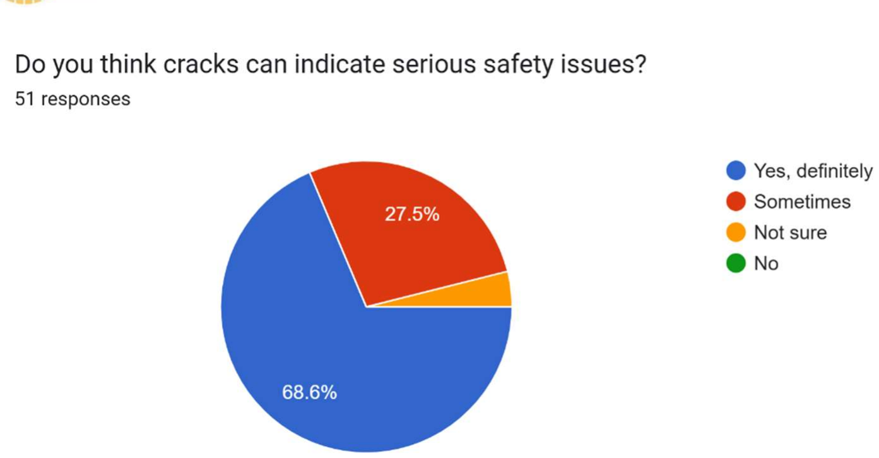
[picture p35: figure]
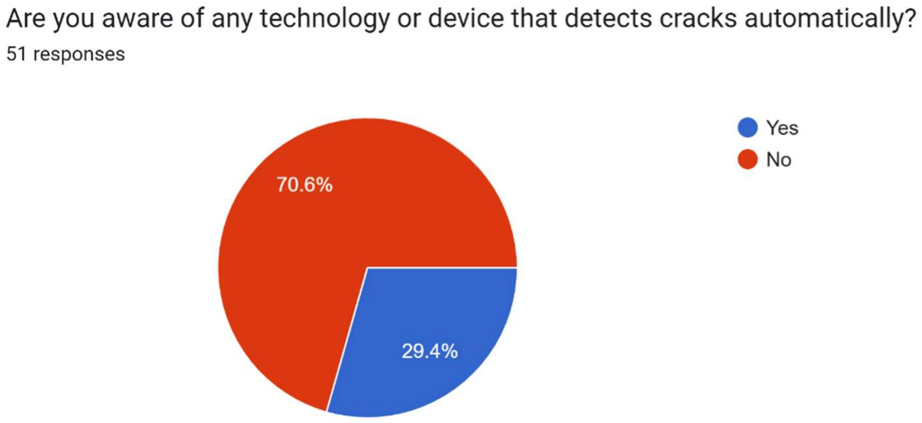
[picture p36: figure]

11

Figure 7. Perception of cracks as potential safety issues

Figure 8. Awareness of existing crack detection technologies

Taking together the findings suggest that a substantial majority of people are already conscious of cracks—virtually everyone has spotted one at some point. Many encounter them on a basis.. The prevailing tendency is to look the way rather than flag the problem even though most respondents acknowledge that cracks can herald serious structural issues. Moreover a notable share of those surveyed admitted they were unaware of any existing detection technology underscoring the opportunity, for a accessible system like SSC‑DMS to bridge a significant gap, in both awareness and reporting.

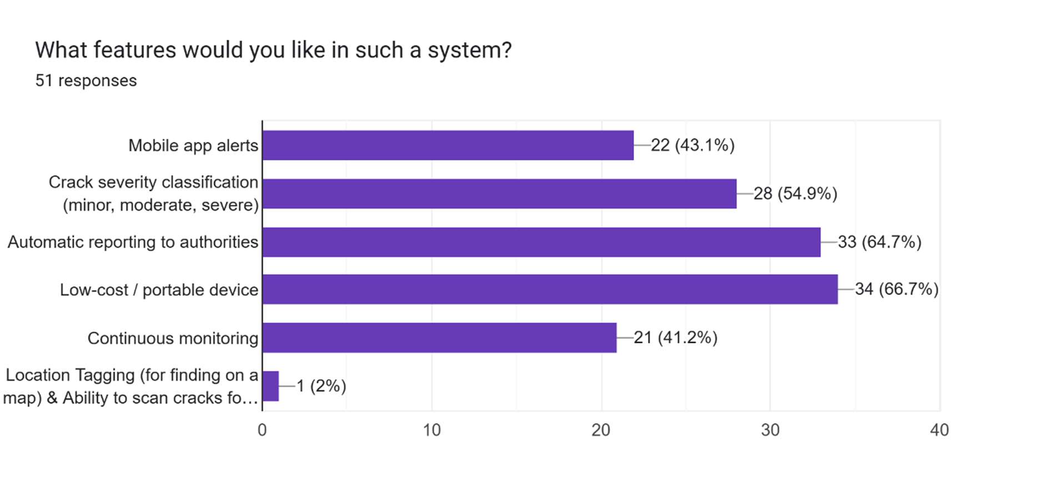
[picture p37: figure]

12

FEATURE PRIORITIES

To identify which features people would find most useful in a crack-detection system, we asked participants what options they would like included.

Figure 9. Preferred features in a crack detection system

The survey data point to two features that topped the wish‑list: a device—chosen by 66.7 % of respondents—and an automatic reporting link, to authorities favored by 64.7 %. Those numbers underline an appetite for a low‑priced tool that can seamlessly flag safety issues. Moreover a little more, than half of the participants (54.9 %) also called for a crack‑severity classification hinting that users would value a system of telling whether a crack is merely superficial or potentially serious. Mobile‑app alerts (43.1 %) and continuous monitoring (41.2 %) emerged as the cited features while only a modest handful mentioned location‑tagging and scanning capabilities. Taken together the responses highlight that users prioritize accessibility, automation and affordability—three core tenets that will shape the SSC‑DMS prototype’s design.

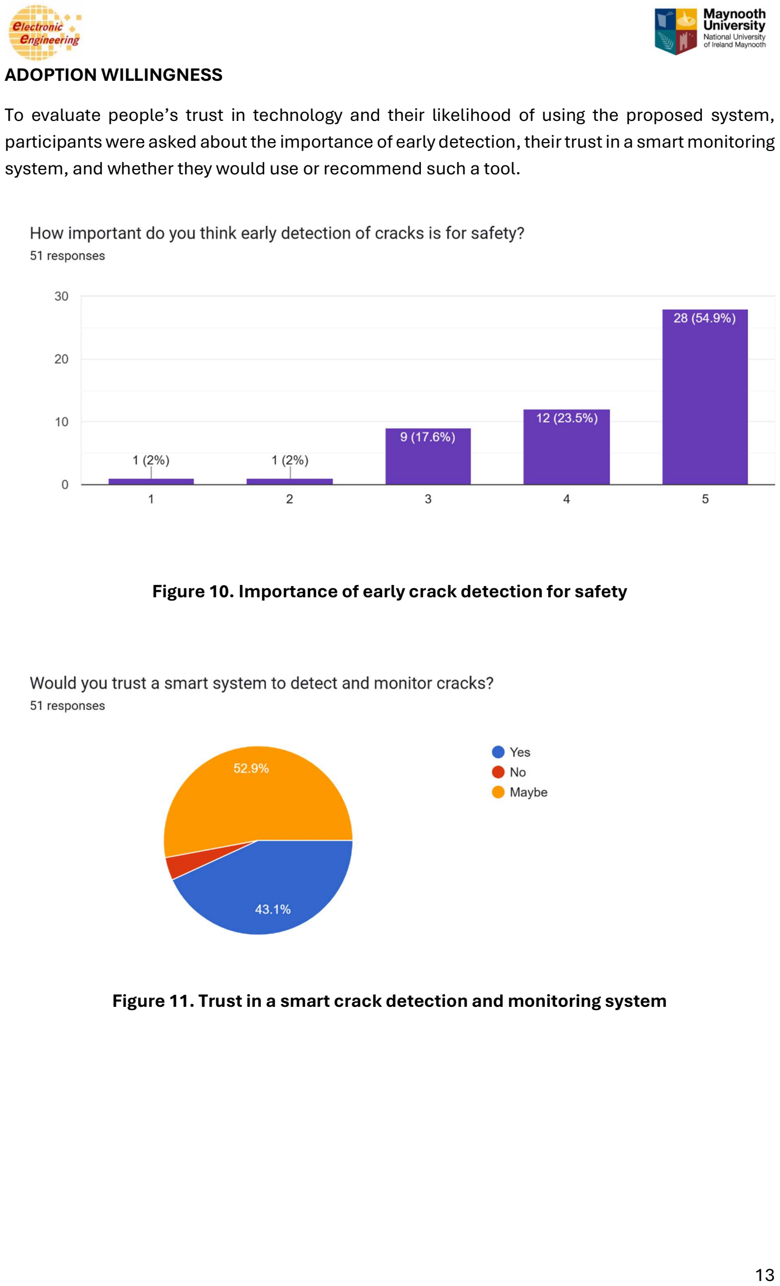
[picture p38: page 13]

13

ADOPTION WILLINGNESS

To evaluate people’s trust in technology and their likelihood of using the proposed system, participants were asked about the importance of early detection, their trust in a smart monitoring system, and whether they would use or recommend such a tool.

Figure 10. Importance of early crack detection for safety

Figure 11. Trust in a smart crack detection and monitoring system

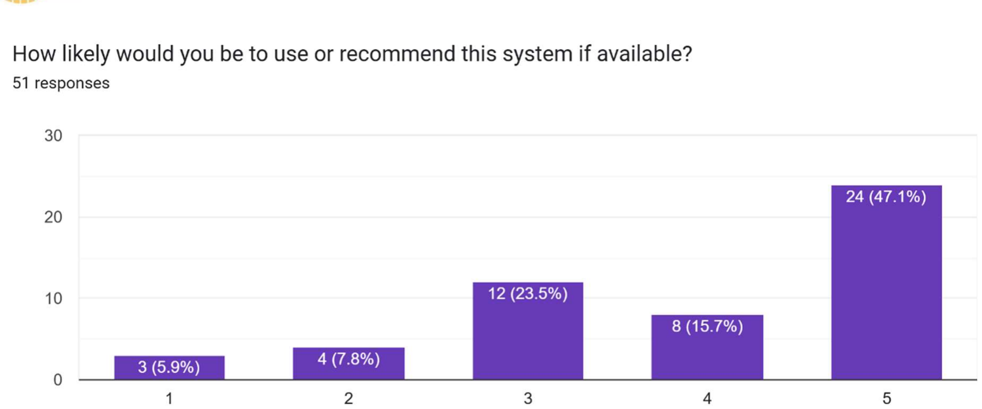
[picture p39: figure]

14

Figure 12. Likelihood of using or recommending the system

In sum the feedback skews decidedly positive. Just, over half of those surveyed—54.9 %—rated crack detection as " important," underscoring a strong safety consciousness. When asked whether a smart detection system would be trusted 43.1 % answered yes. A further 52.9 % responded "maybe " indicating an openness, to new technology if it proves reliable.

Ultimately almost half—47.1%—of those surveyed said they'd be very likely to use or recommend the system once it becomes available. That signals interest and a willingness to embrace affordable accessible options such, as SSC‑DMS especially if the system proves reliable and easy to handle.

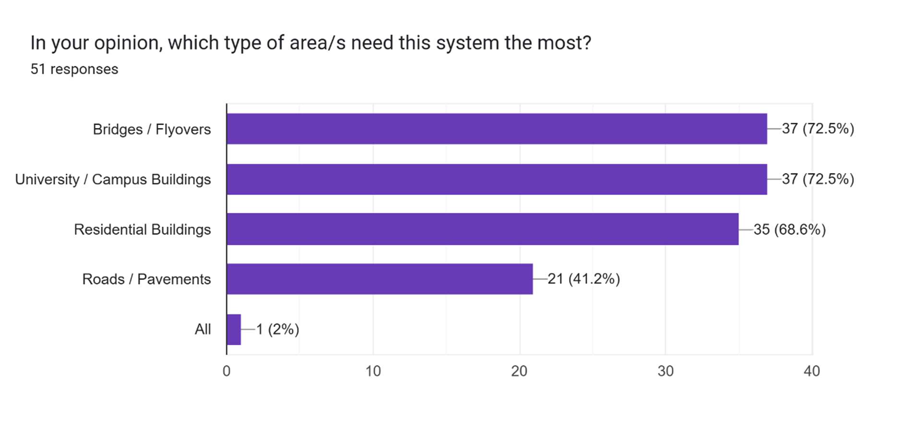
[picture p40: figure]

15

FEEDBACK & APPLICATION AREA

To understand where the proposed crack detection system would have the greatest impact, participants were asked which types of areas or structures they believe need it the most.

Figure 13. Participant opinions on areas most in need of crack detection systems

The survey shows a consensus: bridges and flyovers (72.5 %) and university or campus buildings (72.5 %) are seen as the places most, in need of the system. That mirrors concerns, about safety and the need to keep used or aging structures well maintained.

68.6 % of respondents chose buildings underscoring that they see crack detection, as more, than a purely engineering problem—it’s a concern that reaches into homes and neighborhoods. Roads and pavements attracted 41.2 % of the votes; while deemed urgent they’re still regarded as important especially in areas that see heavy public traffic.

All things considered the feedback points to a well‑founded perception that SSC‑DMS has the flexibility to operate in a variety of arenas—whether it’s the backbone of services or the everyday nooks we frequent—and that academic campuses serve as a proving ground, for crafting and vetting the system.

Lastly, we asked the participants if they had any suggestions or comments about our project idea. A few of the suggestions are listed below:

Any suggestions or comments about our project idea?

- “Very interesting. Will be extremely helpful in preventing accidents”
- “Make sure the system have no bug”
- “Focus on ease of use will make this considerably more attractive. If anyone could find, scan and report a crack for example”
- “If its implemented, it will be easier for people to determine cracks. It will be helpful. Looking forward.”
- “Stear it to a specific type of infrastructure, e.g. buildings or bridges etc. easier if it's not too broad”

16

- “I mainly see this as something you would use for eaither under water earthquake, crack detection in bridge or underwater structure that could be in need of this or used in determining the serverity of a buildings damages, so steps can be taken to either tear down for safty reason or find weekness in certain aspects like week pillers that lost its support function due to crack most building are tought out in its design and meterial so taht it doesnt crack or bend under compression or tension. But we can use tilted tower as example why is it tilted could your device monitor or determin serverity or why this happened and how is there a way that your device can alert early on; so the steps may be taken in preventing such an event early on.”

17

## 4. PROBLEM SPECIFICATION

In the wake of the research and survey the projects ambition is to engineer a Smart Structural Crack Detection & Monitoring System (SSC‑DMS) that not identifies but analyses and classifies cracks, across a range of infrastructure. By marrying image scrutiny with sensing the system aims to uncover both conspicuous surface fissures and hidden internal discontinuities that typically evade visual inspection.

The system will employ a smartphone camera as the means of capturing images of surfaces— walls, pavements or concrete structures. Those pictures will then be processed via image‑processing and machine‑learning techniques to pinpoint the presence of cracks gauge their dimensions and evaluate how severe they are. Complementing the camera sensors such, as vibration detectors will be added to monitor changes, in the material and verify any internal cracks.

All the captured details—crack size, type, location and depth—show up on a interface and get stored digitally for future reference. With that data, in hand trend analysis and maintenance planning become straightforward letting users keep an eye on crack growth over time.

At its core the system pursues three pillars—precision, affordability and broad accessibility. By shaping a prototype that stays inexpensive and easy to carry it opens the door, for not engineers but students maintenance crews and ordinary members of the public to operate it safely and effectively.

In the end the SSC‑DMS is intended to function as a preemptive‑maintenance gadget catching faults early and thus cutting down the odds of a collapse. What the project aims to deliver is an prototype plus a software model that illustrate how on‑the‑fly crack detection and perpetual monitoring can raise safety levels and stretch the functional lifespan of community infrastructure.

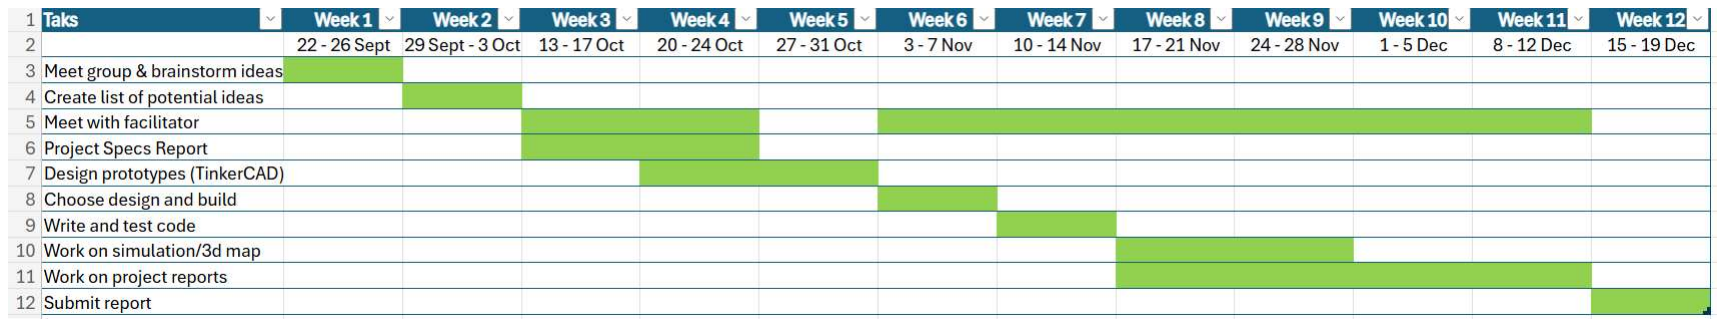
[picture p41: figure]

18

## 5. WORKPLAN & GANTT CHART

In order to effectively manage our project, we created a Gantt chart that outlines our workplan. This will help us keep track of tasks and complete the project and reports before the due date. If for any reason we fall behind or end up ahead of our projected schedule, the Gantt chart can be used to ensure we did not miss any tasks.

The Gantt chart below (Figure 1) details our workplan from the beginning of the semester till the project due date (Monday 15th December). From week 3 to week 11, we will have weekly meetings with our facilitator, Vahid Fakhari. From previous projects we know how valuable regular advice and feedback is to a good project. An agenda is created before each meeting and minutes are taken during the meeting. We will not have scheduled lab time to work on the project in week 5 as it’s a study week. However, progress can still be made as we develop various prototypes online using TinkerCAD. Towards the end of the project, we will work on the technical report as we finish up the project. This will give us enough time to produce a thorough and well thought out report without the stress of a looming deadline. As a group we are confident we can stick to our guideline and present a successful project within the given timeline.

Figure 14 – Gantt Chart

19

## 6. CONCLUSION

This study set out to examine the mounting demand, for practical easy‑to‑use methods of health monitoring across both private infrastructure. By combing through research and parsing survey responses we discovered that cracks rank among the common and worrisome structural issues reported by the public. Nevertheless many people. Overlook these fissures. Simply lack knowledge of how to address them and few have access, to tools capable of detecting them accurately.

Our deep dive, into the tech there—ultrasonic testing rigs, LiDAR scanners and a host of data‑recording setups—served up a double dose of insight: a litany of constraints that hobble current crack‑detection methods and a glimpse of the untapped promise they still hold. It also underscored an opening for a kit that fuses smartphone‑based visual analysis with sensor input, a hybrid that could span the chasm, between specialist inspection gear and grassroots community‑level awareness.
The latest poll of respondents reaffirmed that a sizable slice of the sample grasps the stakes of catching cracks and is inclined to adopt a detection kit provided the price is modest and the interface is intuitive. That finding amplifies the weight of our venture. Spotlights the pressing demand, for fresh breakthroughs, in this niche.

As progress continues the Smart Structural Crack Detection & Monitoring System (SSC‑DMS) aims to meld camera‑based image processing, ultrasonic sensing and straightforward data‑logging into a device. This integration could streamline inspections reinforce safety and support preventive‑maintenance initiatives.

In sum our work illustrates that fusing sensing techniques, AI‑driven analysis and community participation can deliver a high‑impact remedy for a long‑standing engineering hurdle. With refinement the SSC‑DMS could evolve into a tool, for protecting and prolonging the life of infrastructure across university campuses, local communities and even farther afield.

20

## 7. REFERENCES

[1] Infrastructure Definition INFRASTRUCTURE Definition & Meaning - Merriam-Webster (accessed October 2025).
[2] Bridge under construction in China collapses into Yellow River, killing at least 12 people, state media say Bridge under construction in China collapses into Yellow River, killing at least 12 people, state media say - CBS News (accessed October 2025).
[3] Bangkok Sinkhole: Soil entered metro tunnel due to damaged station ceiling, says governor
Bangkok sinkhole: Soil entered metro tunnel due to damaged station ceiling, says governor | The
Straits Times (accessed October 2025).
[4] Non-Destructive Testing (NDT) – Process, Types & Applications Explained Non-Destructive
Testing (NDT) | Process, Types & Applications | Fractory (accessed October 2025).
[5] What is LiDAR? What is LiDAR? | IBM (accessed October 2025).
[6] Lidar System Architectures and Circuits Lidar System Architectures and Circuits | IEEE
Journals & Magazine | IEEE Xplore (accessed October 2025).
[7] 3D Vision Technologies for a self-developed structural external crack damage recognition robot 3D vision technologies for a self-developed structural external crack damage recognition robot - ScienceDirect (accessed October 2025).
[8] Structural Crack Detectors Crack Detectors - GAO Tek (accessed October 2025).
[9] Types of ultrasonic testing displays: A-scan B-scan and C-scan Types of ultrasonic testing Displays: A-scan B-scan and C-scan (accessed October 2025).
[10] LiDARsim: Realistic LiDAR Simulation by Leveraging the Real World LiDARsim: Realistic
LiDAR Simulation by Leveraging the Real World | IEEE Conference Publication | IEEE Xplore
(accessed October 2025).
[11] Multifunctional Magnetic Particle Flaw Detector Magnetic Particle Crack Detector Alibaba.com (accessed October 2025).
[12] IDEA2D NDT Portable Eddy Current Crack Detector Alibaba.com (accessed October 2025).

21

## 8. APPENDIX

### Appendix A: Survey Responses

Note: Although all responses are anonymous, each respondent is someone who has experience in construction, engineering, manufacturing, etc. The sample covered various levels of expertise, ranging from DIY home projects to industry professionals.

Survey Response 1

### 1. Are you aware of any technology or device that detects cracks?

No, I have never used a device like that.

### 2. Would you trust a device to detect cracks?

Yes, I've used devices like stud detectors before, and they work well.

### 3. Which of these features would you like in such a device?

a. Crack severity classification (minor, moderate, severe)
b. Record and store data from session to playback later
c. Low cost
d. Portable device
e. Continuous monitoring
f. Other (Specify)
c - portable device, d - low cost

### 4. How likely would you be to use this device?

I probably wouldn't use it. I usually just fill cracks at home without giving it too much thought so I wouldn't really be interested in getting one.

### 5. Where would you use this device?

I'm not in construction or anything like that by profession so I would probably only use it at home if I had to get one.

### 6. Any other comments/suggestions?

How much would a device like this usually cost?
Responded: The lowest price I’ve seen is about €100.

Survey Response 2

### 1. Are you aware of any technology or device that detects cracks?

Yes, but I have never used one before.

### 2. Would you trust a device to detect cracks?

Yes, especially when it’s not easy to see, like inside a material.

### 3. Which of these features would you like in such a device?

a. Crack severity classification (minor, moderate, severe)
b. Record and store data from session to playback later
c. Low cost
d. Portable device
e. Continuous monitoring
f. Other (Specify)

22

a – severity classification, c – low cost, d – portable, e – continuous monitoring

### 4. How likely would you be to use this device?

Yes, it would be useful for work.

### 5. Where would you use this device?

I would use it at work my workplace and at home for personal projects.

### 6. Any other comments/suggestions?

No

Survey Response 3

### 1. Are you aware of any technology or device that detects cracks?

Yes, I’ve used tech like that.

### 2. Would you trust a device to detect cracks?

Yes, technology is always more reliable than people.

### 3. Which of these features would you like in such a device?

a. Crack severity classification (minor, moderate, severe)
b. Record and store data from session to playback later
c. Low cost
d. Portable device
e. Continuous monitoring
f. Other (Specify)
d – portable, f – Other: highly accurate and reliable

### 4. How likely would you be to use this device?

Very likely, but only if I found it better than the equipment I use now.

### 5. Where would you use this device?

I work in quality assurance, so I use tools like this at work.

### 6. Any other comments/suggestions?

7. It’s very useful to be able to see exactly where a fault is early in production.

Survey Response 4

### 1. Are you aware of any technology or device that detects cracks?

Yes, I know of a couple tools that can detect cracks.

### 2. Would you trust a device to detect cracks?

Yes, manually inspections can be really time consuming.

### 3. Which of these features would you like in such a device?

a. Crack severity classification (minor, moderate, severe)
b. Record and store data from session to playback later
c. Low cost
d. Portable device
e. Continuous monitoring
f. Other (Specify)
a – classification, c – low cost, d - portable

### 4. How likely would you be to use this device?

23

It’s something I would like to have and not need rather than need and not have.

### 5. Where would you use this device?

Probably at home and at work.

### 6. Any other comments/suggestions?

No.

Survey Response 5

### 1. Are you aware of any technology or device that detects cracks?

Yes, but I don’t have one.

### 2. Would you trust a device to detect cracks?

Yes, as long as it’s decently accurate.

### 3. Which of these features would you like in such a device?

a. Crack severity classification (minor, moderate, severe)
b. Record and store data from session to playback later
c. Low cost
d. Portable device
e. Continuous monitoring
f. Other (Specify)
c – low cost, d - portable

### 4. How likely would you be to use this device?

I would use it if I had one.
Responded: Why don’t you have one?
I’ve looked at a few devices, but they were a bit out of my price range.

### 5. Where would you use this device?

I would use it at work.

### 6. Any other comments/suggestions?

No.

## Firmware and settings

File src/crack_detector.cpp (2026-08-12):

/*
 * Ultrasonic Crack Detection
 * EE397 Technical Report, Group 5 — Maynooth University, Dec 2025
 *
 * HC-SR04 swept across a surface. A crack shows as a spike in the
 * distance reading, visible live in the Arduino IDE serial plotter.
 */

int trig = 3;
int echo = 2;
long duration;    // echo pulse width
float distance;   // measured distance, cm

void setup() {
  pinMode(trig, OUTPUT);
  pinMode(echo, INPUT);
  Serial.begin(9600);
}

void loop() {
  distance = calcDistance();
  Serial.print("Distance = ");
  Serial.println(distance);
  delay(300);
}

float calcDistance() {
  digitalWrite(trig, LOW);
  delayMicroseconds(2);

  digitalWrite(trig, HIGH);   // 10 us trigger pulse
  delayMicroseconds(10);
  digitalWrite(trig, LOW);

  duration = pulseIn(echo, HIGH);
  distance = (duration * 0.034) / 2;   // speed of sound, halved for round trip
  return distance;
}
